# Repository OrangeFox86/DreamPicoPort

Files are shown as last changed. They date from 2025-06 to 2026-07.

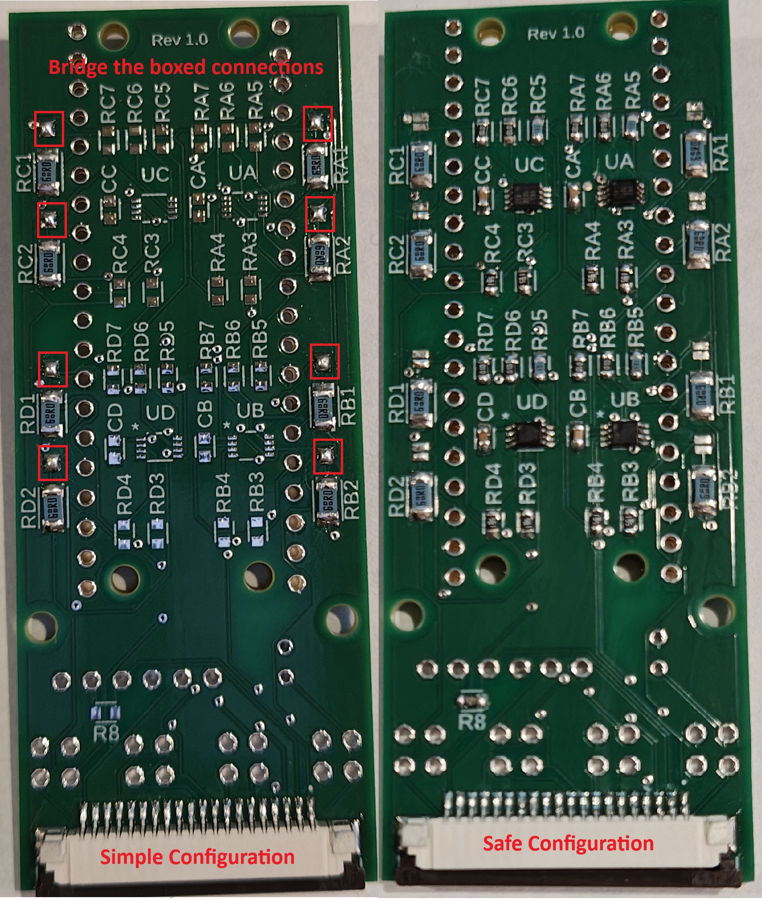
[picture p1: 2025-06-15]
pcb/board-examples.jpg

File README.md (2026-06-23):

# DreamPicoPort (formally DreamcastControllerUsbPico)

Using a Raspberry Pi Pico, DreamPicoPort enables USB interfacing with a Dreamcast or its controllers and peripherals, functioning in either host mode or client mode as depicted below.

Looking for instructions on how to use this with flycast? [Bring me to it!](https://github.com/OrangeFox86/DreamPicoPort/wiki/*-Host-Mode-Installation-Guide-(for-use-with-Flycast))

| Host Mode | Client Mode |
| --- | --- |
| host mode | client mode |

This platform may easily be forked and adapted for other interfacing needs. Feel free to do so under the conditions of the supplied [LICENSE.md](LICENSE.md).

Refer to the [releases](https://github.com/OrangeFox86/DreamPicoPort/releases) page for current progress. Refer to the [issues](https://github.com/OrangeFox86/DreamPicoPort/issues) tab for things left to be implemented and known bugs.

---

# General Disclaimer

Proceed at your own risk! I am not liable for any damage that may occur due to the use of any provided schematics, firmware, or any other recommendations made within this project (see [LICENSE.md](LICENSE.md)). There is risk of damage to any attached hardware (ex: USB port, Dreamcast peripheral, or Dreamcast) if circuitry is improperly handled.

---

# Quick Installation Guide

These instructions have been moved to [the wiki](https://github.com/OrangeFox86/DreamPicoPort/wiki/Installation-Guide).

# Build Instructions (for Linux and Windows)

If running under Windows, install [WSL](https://docs.microsoft.com/en-us/windows/wsl/install) and your desired flavor of Linux. I recommend using Ubuntu 22.04 as that is what I have used for development. Then the steps below may be run within your WSL instance.

1. Install git, cmake, and gcc-arm-none-eabi compiler by running the following commands
```bash
sudo apt update
sudo apt -y install git cmake gcc-arm-none-eabi
```

2. (optional) In order to run and debug tests, install standard gcc compilers and gdb by running the following
```bash
sudo apt -y install build-essential gdb
```

3. Clone this repo then cd into the created directory
```bash
git clone https://github.com/Tails86/DreamPicoPort.git
cd DreamPicoPort
```

4. Pull down the pico SDK (this project now uses a fork of the SDK - it will no longer compile under the standard SDK)
```bash
git submodule update --recursive --init
```
Hint: if you have issues building, the easiest way to correct any submodule synchronization issue is to delete the `ext/pico-sdk` directory (ex: `rm -rf ext/pico-sdk`), restore the directory `git restore ext/pico-sdk`, and then re-run the above submodule update command.

5. (optional) Build and run tests - this runs core lib unit tests locally
```bash
./run_tests.sh
```

6. Execute the build script
```bash
./build.sh
```

After build completes, binaries should be located under `dist/`. Pre-built release binaries may be found [here](https://github.com/OrangeFox86/DreamPicoPort/releases).

This project may be opened in vscode. In vscode, the default shortcut `ctrl+shift+b` will build the project. The default shortcut `F5` will run tests with gdb for local debugging. Open the terminal tab after executing tests with debugging to see the results.

---

# Maple Bus Implementation

The Maple Bus is a serial communications protocol which Dreamcast uses to communicate with controllers and other peripherals. Refer to documentation [here](https://dreamcast.wiki/Maple_bus) for general information about the Maple Bus.

## Why the RP2040/RP2350 are Game Changers for Emulating Communication Protocols

To emulate a bespoke communication protocol such as the Maple Bus on an MCU, one would usually either need to add extra hardware or bit bang the interface. This is not true with the RP2040/RP2350 and their PIO. Think of it as several extra small processors on the side using a special machine language purpose-built for handling I/O. This means communication can be offloaded to the PIO and only check on them after an interrupt is activated or a timeout has elapsed. Check out [maple_in.pio](src/hal/MapleBus/maple_in.pio) and [maple_out.pio](src/hal/MapleBus/maple_out.pio) to see the PIO code.

Luckily, the RP2040/RP2350 come with 2 PIO blocks each with 4 separate state machines. This means that the RP2040/RP2350 can easily emulate 4 separate controller interfaces, each at full speed!

## Interfacing with the PIO State Machines

The [MapleBus class](src/hal/MapleBus/MapleBus.hpp) operates as the interface between the microcontroller's code and the PIO state machines, [maple_in.pio](src/hal/MapleBus/maple_in.pio) and [maple_out.pio](src/hal/MapleBus/maple_out.pio).

Using 2 separate PIO blocks for reading and writing is necessary because each PIO block can only hold up to 32 instructions, and this interface is too complex to fit both read and write into a single block. Therefore, the write state machine is completely stopped before starting the read state machine for the targeted bus. Switching state machines is fast enough that there shouldn't be a problem. Testing showed the handoff always occurs within 1 microsecond after bringing the bus back to neutral. A device on the Maple Bus starts responding some time after 50 microseconds from the point of the bus going neutral after an end sequence. This ensures that a response is always captured.

The following lays out the phases of the state machine handled within the MapleBus class.

<p align="center">
  MapleBus Class State Machine
</p>

### PIO Data Handoff

When the write method is called, data is loaded into the Direct Memory Access (DMA) channel designated for use with the maple_out state machine in the MapleBus instance. The DMA will automatically load data onto the TX FIFO of the output PIO state machine so it won't stall waiting for more data.

The first 32-bit word loaded onto the output DMA is how many transmission bits will follow. In order for the state machine to process things properly, `(x - 8) % 32 == 0 && x >= 40` must be true where x is the value of that first 32-bit word i.e. every word is 32 bits long and at least a frame word (32 bits) plus a CRC byte (8 bits) are in the packet. This value needs to be loaded with byte order flipped because byte swap is enabled in the DMA so that all other words are written in the correct byte order. The rest of the data loaded into DMA is the entirety of a single packet as a uint32 array. The last uint32 value holds the 8-bit CRC.

A blocking IRQ is triggered once the maple_out state machine completes the transfer. This then allows MapleBus to stop the maple_out state machine and start the maple_in state machine.

A Direct Memory Access (DMA) channel is setup to automatically pop items off of the RX FIFO of the maple_in state machine so that the maple_in state machine doesn't stall while reading. Once the IRQ is triggered by the maple_in state machine, MapleBus stops the state machine and reads from data in the DMA.

## Generating Maple Bus Output

The [maple_out PIO state machine](src/hal/MapleBus/maple_out.pio) handles Maple Bus output. Data is generated by following the signal definition [here](https://dreamcast.wiki/Maple_bus#Maple_Bus_Signals).

## Sampling Maple Bus Input

The [maple_in PIO state machine](src/hal/MapleBus/maple_in.pio) handles Maple Bus input. Some concessions had to be made in order to handle all input operations within the 32 instruction set limit of the input PIO block. The following are the most notable limitations.
- Only a standard data packet may be sampled
    - The Maple Bus protocol has different types of packets depending on how many times B pulses in the start sequence, but those packets are ignored in this implementation
- The full end sequence is not sampled
    - The packet length in the frame word plus the CRC are relied upon during post-processing in order to verify that the received packet is valid

### Sampling the Start Sequence

The input PIO state machine will wait until **A** transitions LOW and then count how many times **B** toggles LOW then HIGH while making sure **A** doesn't transition HIGH until after **B** transitions HIGH. If the toggle count isn't 4, then the state machine keeps waiting. Otherwise, the state machine signals the application with a non-blocking IRQ and continues to the next phase where data bits are sampled.

### Sampling Data Bits

For each bit, the state machine first waits for the designated clock to be HIGH before proceeding. Then once this line transitions to LOW, the state of the designated data line is sampled. State transitions of the designated data line are ignored except for the case when sensing the end sequence is required as described in the next section.

### Sampling the End Sequence

Whenever **A** is designated as the clock, the input PIO state machine will detect when **B** toggles HIGH then LOW while **A** remains HIGH. It is assumed that this is the beginning of the end sequence since this is not a normal behavior during data transmission. The state machine will then block on an IRQ so that the application can handle the received data.

---

# Appendix A: Abbreviations and Definitions

- `0x` Prefix: The following value is hex format
- Byte: Data consisting of 8 consecutive bits
- DMA: Direct Memory Access
- LSB: Least Significant Byte
- LSb: Least Significant bit
- MSB: Most Significant Byte
- MSb: Most Significant bit
- Nibble: Data consisting of 4 consecutive bits
- PIO: Programmable Input/Output
- SDCK: Serial Data and Clock I/O
- Word: Data consisting of 32 consecutive bits

---

# External Resources

**Maple Bus Resources**

https://archive.org/details/MaplePatent/page/n7/mode/1up

http://mc.pp.se/dc/maplebus.html and http://mc.pp.se/dc/controller.html

https://tech-en.netlify.app/articles/en540236/index.html

https://www.raphnet.net/programmation/dreamcast_usb/index_en.php

https://web.archive.org/web/20100425041817/http://www.maushammer.com/vmu.html

https://hackaday.io/project/170365-blueretro/log/180790-evolution-of-segas-io-interface-from-sg-1000-to-saturn

https://segaretro.org/History_of_the_Sega_Dreamcast/Development

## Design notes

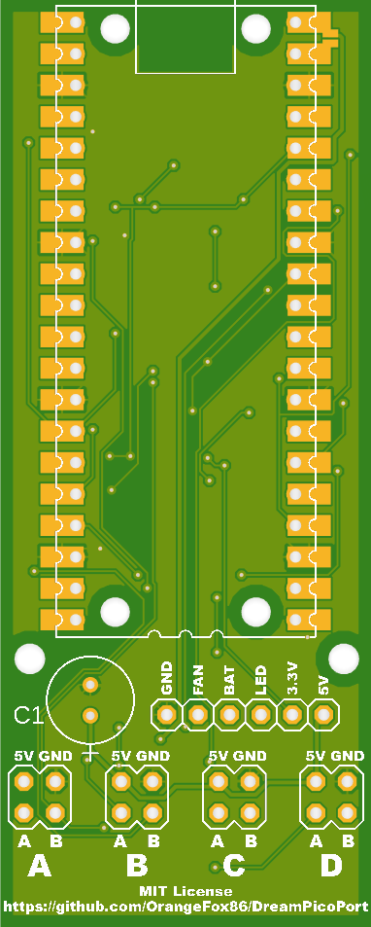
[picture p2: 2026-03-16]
pcb/board-top.png

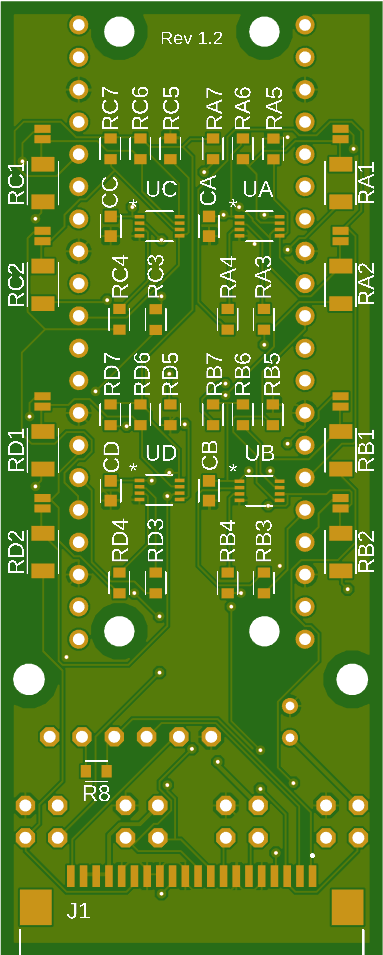
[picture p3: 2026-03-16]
pcb/board-bottom.png

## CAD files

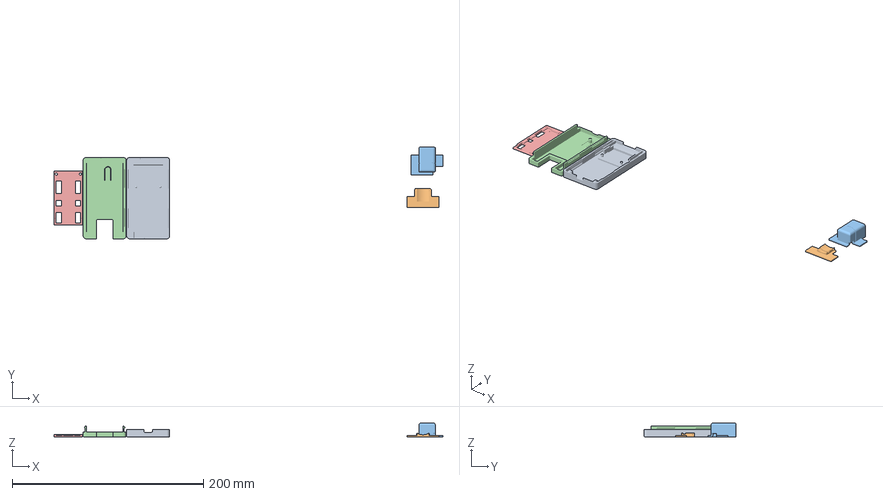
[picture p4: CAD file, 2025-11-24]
3d_objects/DPP-Case-1P-BambuStudio.3mf
406.7 x 95.8 x 15.0 mm
DPP-Case-Bottom
DPP-Case-DC-Connector-Bottom
DPP-Case-DC-Connector-Top
DPP-Case-Top
DPP-Dummy-Board

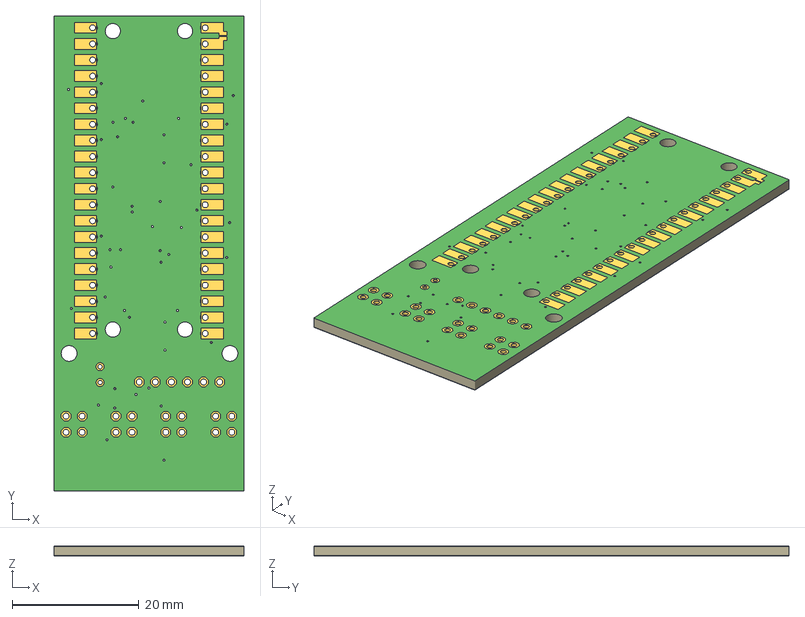
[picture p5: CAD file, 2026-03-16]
pcb/DreamPicoPortSchem.3mf
30.0 x 75.0 x 1.64 mm
Board
CopperHoles

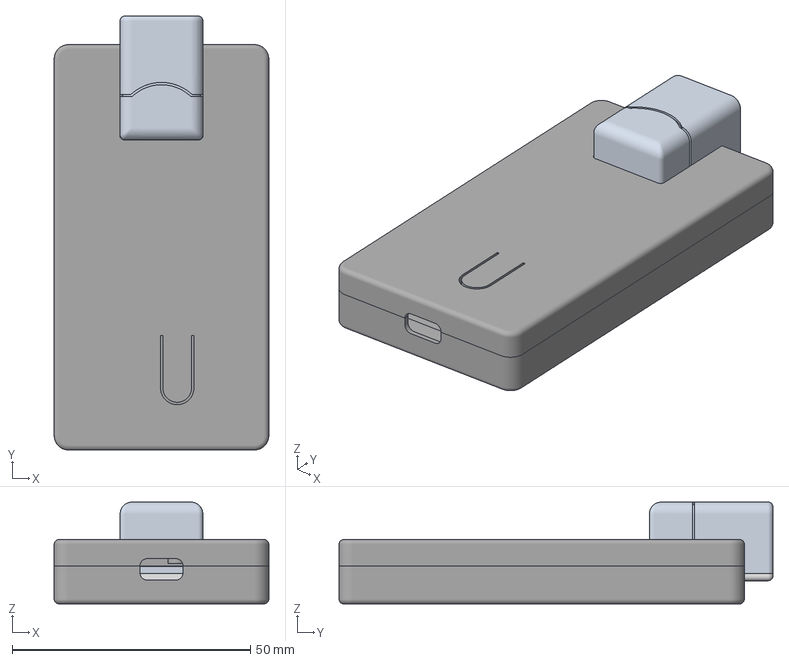
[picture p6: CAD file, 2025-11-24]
3d_objects/DPP-Case-1P-raw.3mf
45.0 x 91.0 x 21.4 mm
DPP-Case-Bottom
DPP-Case-DC-Connector-Bottom
DPP-Case-DC-Connector-Top
DPP-Case-Top

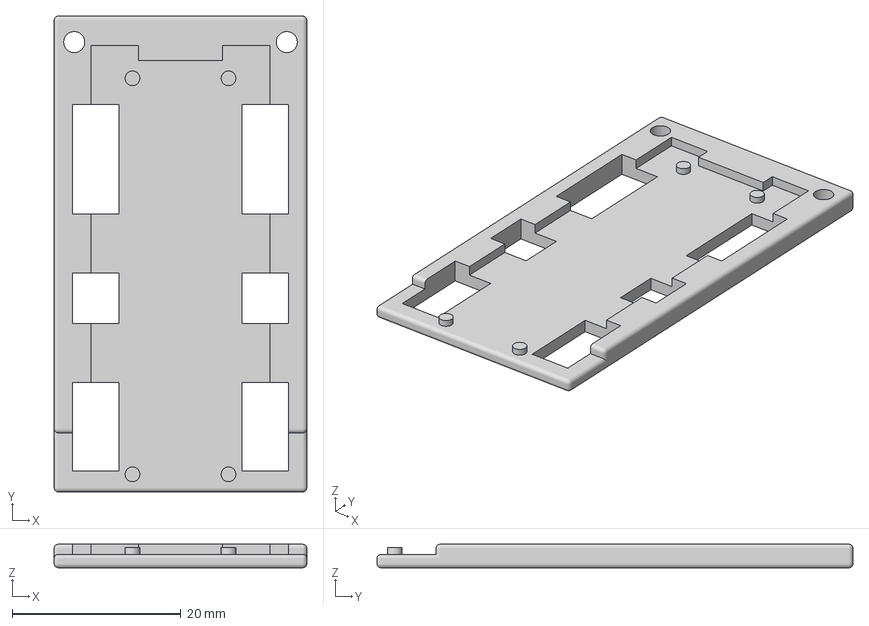
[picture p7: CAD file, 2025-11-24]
3d_objects/DPP-Dummy-Board-raw.3mf
30.0 x 56.5 x 2.80 mm

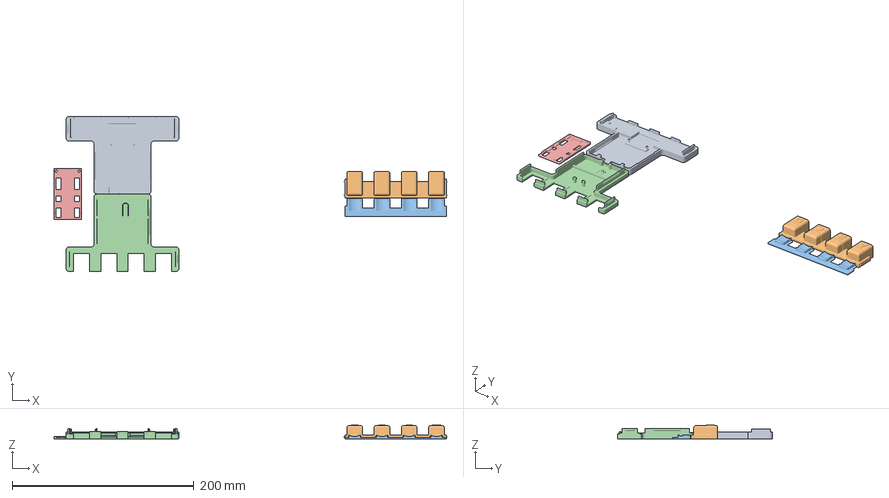
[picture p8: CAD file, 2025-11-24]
3d_objects/DPP-Case-4P-BambuStudio.3mf
432.5 x 170.5 x 15.6 mm
DPP-Case-4P-Bottom
DPP-Case-4P-DC-Connector-Top
DPP-Case-4P-DC-Connector-Bottom
DPP-Case-4P-Top-Solid
DPP-Dummy-Board

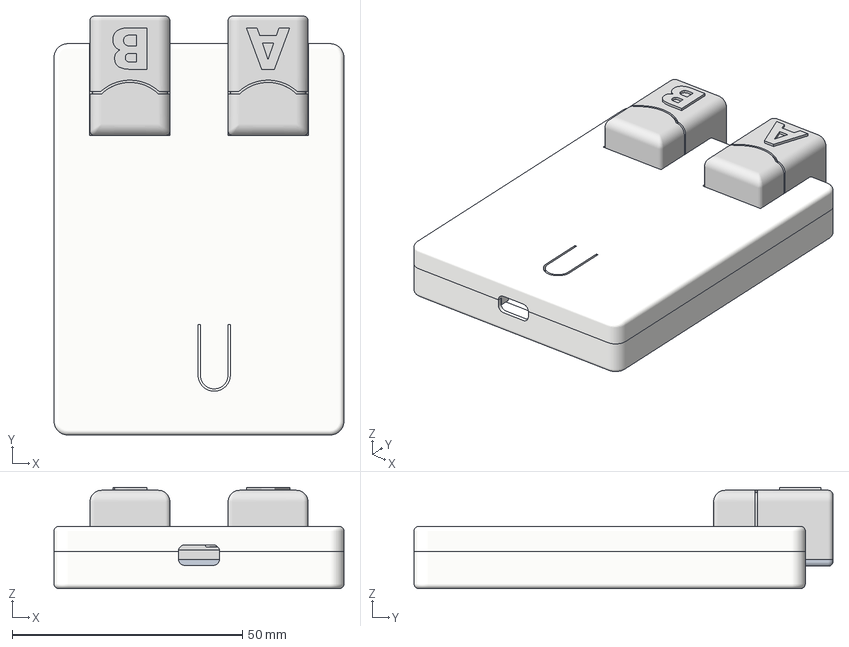
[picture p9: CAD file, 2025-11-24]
3d_objects/DPP-Case-2P-raw.3mf
63.0 x 91.0 x 21.9 mm
DPP-Case-2P-Bottom
DPP-Case-2P-DC-Connector-Bottom
DPP-Case-2P-DC-Connector-Top
DPP-Case-2P-Top-Solid

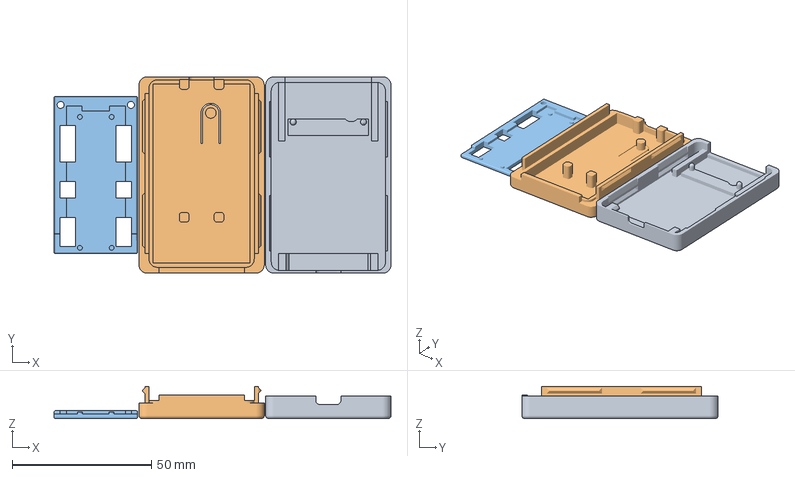
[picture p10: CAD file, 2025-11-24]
3d_objects/DPP-Case-Ribbon-BambuStudio.3mf
121.0 x 70.5 x 11.5 mm
DPP-Case-Ribbon-Bottom
DPP-Case-Ribbon-Top
DPP-Dummy-Board

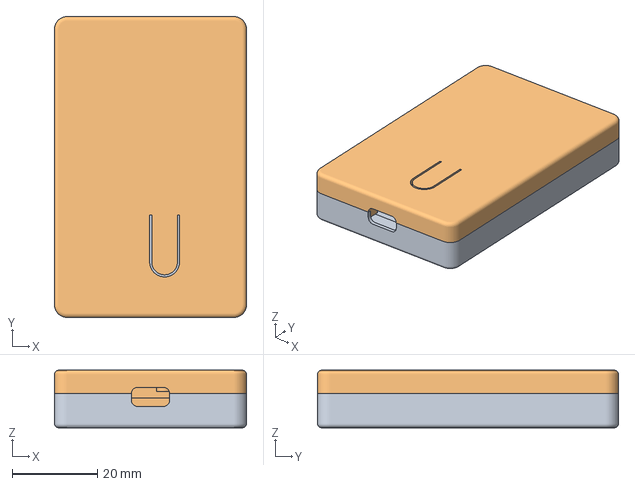
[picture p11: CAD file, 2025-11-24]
3d_objects/DPP-Case-Ribbon-raw.3mf
45.0 x 70.5 x 13.5 mm
DPP-Case-Ribbon-Bottom
DPP-Case-Ribbon-Top

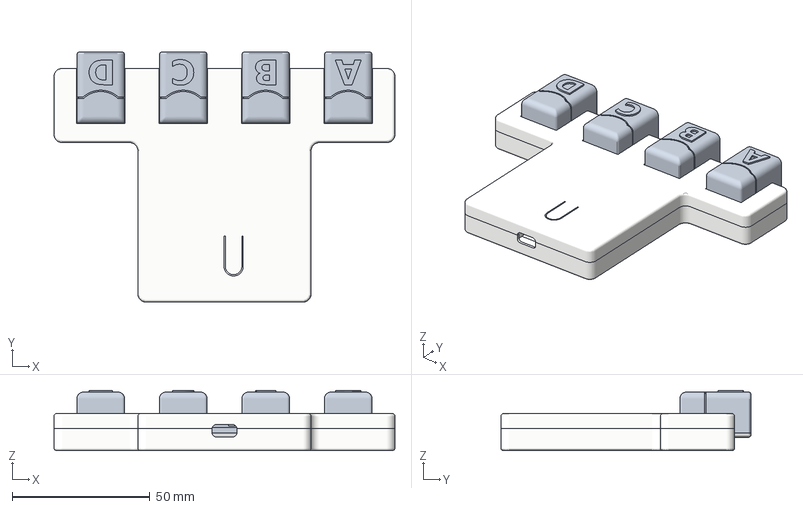
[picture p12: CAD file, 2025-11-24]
3d_objects/DPP-Case-4P-raw.3mf
124.0 x 91.0 x 21.9 mm
DPP-Case-4P-Bottom
DPP-Case-4P-DC-Connector-Bottom
DPP-Case-4P-DC-Connector-Top
DPP-Case-4P-Top-Solid

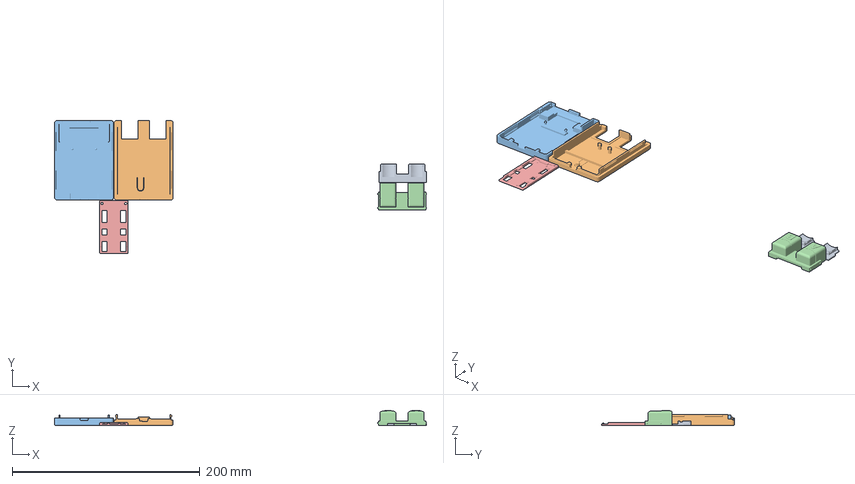
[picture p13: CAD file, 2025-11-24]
3d_objects/DPP-Case-2P-BambuStudio.3mf
396.5 x 142.0 x 15.6 mm
DPP-Case-2P-DC-Connector-Bottom
DPP-Case-2P-Top-Solid
DPP-Case-2P-Bottom
DPP-Case-2P-DC-Connector-Top
DPP-Dummy-Board

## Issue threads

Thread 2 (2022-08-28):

Removing and reinserting VMU occasionally causes communication to fail

Tails86, 2022-08-28:
To reproduce:

- Plug in controller
- Plug VMU (without battery) into controller, and wait until power on beep completes
- Remove VMU
- Repeat above two until controller stops responding completely

Tails86, 2022-08-28:
When a VMU is plugged in and initially powers up, the controller completely stops communicating for a while. Normally, the microcontroller will detect this and internally disconnect then continually ask for status until it responds again. This matches how the Dreamcast operates. Unlike the Dreamcast, this implementation sometimes puts the controller in a non-functioning state until it is reset. One peculiar thing I noticed is during the VMU initialization beep, logic LOW sits about 1.3 to 1.4 V when measuring SDCK lines at the controller. On the Dreamcast, the same sort of oddness happens, but logic LOW sits about 1.0 to 1.1 V. This could be because I'm using slightly higher inline resistors??? I'll try reducing these values later and see if that helps.

Tails86, 2022-08-28:
Changing resistor values makes no difference

Tails86, 2022-09-04:
Occasionally sending reset sequence resolves this. I tested this in the "Add-Reset" branch. This implementation became stale, and I wasn't satisfied with how it was implemented anyway. I'll add this in sometime in the future

Tails86, 2022-09-05:
I found that the pico has some resistance on its output already. I reduced the added resistance on the GPIO to match the total resistance that a Dreamcast has. This didn't seem to help much.

I then played around with a real Dreamcast and was actually able to reproduce this issue there. Since this is an issue on a real system too, I don't think there is much I can do about it. I'm keeping this issue open though so I can keep thinking of ways this can be fixed.

Tails86, 2023-01-02:
The supposed reset sequence, 14 pulses on msckb while mscka is low, does not do anything to get the controller out of this state

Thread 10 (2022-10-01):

Add USB Mass Storage Device for VMU Memory

Tails86, 2022-10-01:

hpx1984, 2022-11-18:
Hi Sir
how to use this function?

Tails86, 2022-11-18:
It's an open item. I haven't done any development for it yet, but I
envision setting up a mass storage device with maybe directory structure of
all files found. Or maybe just the raw data files of each VMU which could
then be imported into an emulator.

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

Tails86, 2022-11-20:
I'm diving into it now - probably another week or two, depending on how much free time I find. FAT16 drive is setup with placeholders for the raw memory files. It's very likely that these files can be dumped right to/from redream vmu bin files (haven't checked that yet, but the file size of redream files is exactly the size of memory available in a VMU).
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

Tails86, 2022-11-25:
I tweaked things a bit so that files only show up when the associated memory unit is attached. I confirmed that the file is compatible with redream. Files at the moment are read only.

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

Closed 2022-11-25.

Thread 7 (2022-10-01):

Host: Add USB HID Gamepad Force Feedback for Vibration

Tails86, 2022-10-01:

Tails86, 2023-01-01:
I was able to get the right FFB descriptors, but it seems like at least Windows is not picking it up/using it correctly. Drivers may be needed.

Tails86, 2023-11-19:
I've struggled with this and failed to come up with anything. Implementing as XInput is likely the best path forward.

Closed 2023-11-19.

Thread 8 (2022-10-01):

Host: Interface Screen to USB

Tails86, 2022-10-01:

Tails86, 2025-03-17:
Moving forward with current direct Flycast integration, so this is no longer necessary

Closed 2025-03-17.

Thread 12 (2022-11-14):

DC controller no functional when test in Window10 and XP's game controller test App

hpx1984, 2022-11-14:
Dear Sir

i used p2040 board and Main.uf2, when this board to PC(connect 1set DC controller on the board) ,the game controller test app can saw 4items "4P"
but my DC controller no functional on game controller test APP
please help me for fix it if you did know how to fix the problem
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

Tails86, 2022-11-14:
Thank you for your interest in this project!

I assume you are using this release, right? https://github.com/OrangeFox86/DreamcastControllerUsbPico/releases/tag/v0.1

The LED on the board should be on once connected to USB and off when any button is pressed on the controller or the analog stick is moved. That should be a quick test to make sure basic controller communication is working.

I have been mainly using Windows 11 to develop this and https://gamepad-tester.com/ to quickly test things out. You should see P1, P2, P3, P4 there and pressing buttons should register.

I have a feeling that Windows is going to have trouble labeling the 4 controllers right in some circumstances (possibly with older versions) which is why it looks like P4 is labeled for all on your system. I may put in a fix in the future to only enumerate connected controllers so that it will at least look fine when a single controller is connected. I can get you a custom single player variant of the uf2 in the meantime if it seems like that is the issue here. How many controllers are you trying to wire up at the moment?

hpx1984, 2022-11-14:
Hi Sir,
thanks your replied any supported ,
yes， i used this FW on my board
the LED always on when i pressed any button
i want connect 4 controllers but at the first i just connected one for test , if it is working fine then i will go on for connect more controller
i used a controller extension cable for soldered on PI Board and then connected my 1st controller on it

i got this but still no action on the page when i pressed button
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

Tails86, 2022-11-14:
Looks like that page enumerates the controller properly. So far so good!

It sounds like you're not getting communication with the controller.

Check your wiring. You made me realize that I forgot to document the pinout at the port. Refer to the image here: http://www.raphnet-tech.com/products/dreamcast_usb_circuit/dc_connector_pinout.png
1: SDCKA
2: +5V
3: GND
4: GND
5: SDCKB

That should correlate to the schematic here:
https://raw.githubusercontent.com/OrangeFox86/DreamcastControllerUsbPico/main/images/schematic.png

hpx1984, 2022-11-15:
hi Sir
double checked the connection it is correct
now i cut the extension cable for short the cable on connection but the system still not working,
any i tried two boards also got same problem
maybe i need to dis-assemble the controller for make sure it is the sega official controller
i had 8sets DC controller on hand but all can't working on this system , but its is working on DC
i will try to find where the problem ,if you have any comment please also let my know for try

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

Tails86, 2022-11-15:
I see where the confusion is. The schematic I used called out physical pin numbers, not the GPIO pin numbers. The top image is what my schematic was drawn for.
14 -> GP10
15 -> GP11
16 -> GP12
17 -> GP13
24 -> GP18
25 -> GP19
26 -> GP20
27 -> GP21
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

Looks like the bottom one you're using lists out the actual GPIO pin numbers, so 10-13 and 18-21 would be the right pins on that one.

I'll update my schematic to make that clearer as well.

hpx1984, 2022-11-15:
Hi Sir

Great
now the system can working，many thanks your great help

now seems perfect if can fix the 4-P4 issue

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

Tails86, 2022-11-15:
I've seen this happen before when using generic HID gamepad descriptors, and it seems to be a long-known bug with Windows DirectX/drivers from forum posts I have gone through. It still happens in Windows 11 now that I've actually looked. What's worse is that Windows doesn't even seem to sort them in the proper order. I'm assuming that the web interface is grabbing raw data instead of going through DirectX which is why things show up properly at gamepad-tester.com.

I _think_ my only options here would be to either use a different USB descriptor for the device like xinput or spin up my own driver. Using xinput seems to be what most controller manufacturers are doing these days in order to avoid writing drivers. I started playing with xinput, but then I got distracted with other things. It will likely be a few more months before this gets fixed.

[This project](https://github.com/fluffymadness/tinyusb-xinput) will likely be very helpful.

hpx1984, 2022-11-18:
many thanks your quickly support ，Sir
the function is good that is first important, so this just a very smaller problem

but this project really a great project for let peoples enjoy DC game on PC like DC console
and this project has great potential as one day it may grow to a family project for support other game console ,like PSXControllerUsbPico, NGCControllerUsbPico, N64ControllerUsbPico,PCEControllerUsbPico,3DOControllerUsbPico...........
hope can see in future

Tails86, 2022-11-27:
Opened up https://github.com/OrangeFox86/DreamcastControllerUsbPico/issues/18 to fix that bug, and I'm closing this thread out

Closed 2022-11-27.

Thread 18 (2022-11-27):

Windows doesn't parse players 1 through 4 labels properly

Tails86, 2022-11-27:
It seems to be a long-known bug with Windows DirectX/drivers from forum posts I have gone through. It still happens in Windows 11 now that I've actually looked. What's worse is that Windows doesn't even seem to sort them in the proper order. I'm assuming that the web interface is grabbing raw data instead of going through DirectX which is why things show up properly at gamepad-tester.com.

I think my only options here would be to either use a different USB descriptor for the device like xinput or spin up my own driver. Using xinput seems to be what most controller manufacturers are doing these days in order to avoid writing drivers.

[This project](https://github.com/fluffymadness/tinyusb-xinput) will likely be very helpful.

multigamesystem, 2023-11-01:
I'm also seeing similar behaviour in RetroArch via Linux.  Which is breaking functionality please make it so only one controller is recognized when one controller is plugged in.  The same issue is happening that when one controller is plugged in it is automatically set to P4.  I've only wired one controller input up as according to your readme.

Tails86, 2025-01-25:
I'm moving forward with just supporting compatibility through the serial interface to whatever emulator wants to interface with this (flycast support is in dev at the moment, but only for 1p mode). I don't think there is anything that can be done with how Windows handles things.

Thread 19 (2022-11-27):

Windows does not try to re-pull FAT table after UNIT ATTENTION sent

Tails86, 2022-11-27:
When the file system adds or removes a file, it sends UNIT ATTENTION to the host so it knows something changed. Windows, however, does not reread the FAT, even when F5 is pressed. I've found *some* help in resending UNIT ATTENTION until read of FAT is detected, but it only works once. I haven't confirmed if the host is actually receiving UNIT ATTENTION.

Figure out what needs to be done in order to force Windows to recheck the FAT.

Tails86, 2022-12-25:
There seems to be no reliable way to accomplish this. I don't want to force a disconnect, so it may be best just to always show 8 devices when the drive attaches. Trying to read vmu that is not attached should then cause an error.

Tails86, 2022-12-26:
It seems like the consensus on stack overflow and other sites that it is bad practice for a mass storage device to modify itself while attached to the host. Seems right to me 😆 I'm changing the purpose of this issue.

Tails86, 2022-12-26:
Purpose:
- All 8 possible VMUs to be presented to the host when any memory unit is detected
- Host is allowed to modify the FAT in any way it would like as long as it's only trying to create or modify entries which have the same file name as something already on the file system
    - Internally use the FAT as "truth" in order to determine where to write to

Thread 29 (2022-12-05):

Expose raw maple bus communication to USB CDC (serial) device

Tails86, 2022-12-05:
Add feature to communicate directly with the maple bus through a USB CDC device. Make it optional (enabled with a jumper) if it starts to interfere with normal communication.

Closed 2022-12-18.

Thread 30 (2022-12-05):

Host: Support VMU beeps through USB

Tails86, 2022-12-05:

Tails86, 2023-12-09:
I discovered this VMU interface never really worked right with the original - only high pitch tones can be generated through the maple bus interface to a real VMU. This didn't seem to ever be used.

Closed 2023-12-09.

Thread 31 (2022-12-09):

Fault while using Retro Fighters controller

Tails86, 2022-12-09:
To reproduce:

1. Plug in Retro Fighters controller and verify controls are working
2. Wait 15 minutes
3. Check gamepad controls again

Expected response:
Controls no longer working

I haven't experienced this with an OEM controller yet.

Tails86, 2022-12-18:
On failure when SHOW_DEBUG_MESSAGES is enabled, I see the message "P1 disconnected", and then no further communication. No communication is seen on the maple bus at this time. The USB CDC interface still echos data which tells me that the core in charge of USB is still working fine. It's just the core in charge of Maple Bus.

I recorded the Maple Bus output until crash. Communication chugs along fine then randomly crashes as the first 2 bits are being outputted. 15 us later, both lines go back high.

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

Tails86, 2022-12-18:
I ran again with analog recording. This shows that not only is this repeatable, but the slow return back HIGH tells me everything shit the bed rather abruptly - probably returning IO all back to high impedance input.
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

I probably won't be able to figure this out until I hook up a proper debugger (which I've been meaning to do, but I haven't had a reason to do it yet)

Tails86, 2022-12-18:
Issuing "h" to USB CDC after this occurs does nothing which means the maple bus core is indeed locked up

Tails86, 2022-12-18:
I found the issue causing this and committed a temporary fix here: https://github.com/OrangeFox86/DreamcastControllerUsbPico/commit/322c4f4dbb9054719bd1e02a314389a1c1a44df3

I think the problem is that TransmissionTimeliner::writeTask() may hold onto a popped transmission until the Maple Bus gets freed. Meanwhile, it's possible for the node to remove the peripheral from its list (deleting it). This invalidates the pointer that is held within mNextTx. Things would crash once txStarted() is called on the invalid pointer.

Something else is not sitting with me right though. The controller shouldn't have been disconnected in the first place. This seems to happen occasionally with the Retro Fighters controller. Perhaps occasional dropouts should be tolerated?

Closed 2022-12-18.

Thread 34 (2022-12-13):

Add support for all different types of controllers

Tails86, 2022-12-13:
I obtained some documentation on button layout for different controllers - support all different types in the controller peripheral. Apparently, fishing rod DOES need to be handled differently. doh!

Tails86, 2023-01-01:
It looks like all controller definitions overlap, and they will send centered or unpressed values if the button/stick/trigger isn't used. Only changed names.

Closed 2023-01-01.

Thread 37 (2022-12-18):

Look further into Retro Fighters controller

Tails86, 2022-12-18:
Issue #31 addressed an issue by allowing 2 consecutive communication failures. Only on 3rd failure would the controller disconnect. I'm not entirely convinced this is an issue with the controller but instead with the way bits are read (I seem to recall my logic analyzer properly picking up the data when things failed). This issue just serves as a reminder for me to go back and look at any other funny business with bit sampling.

Tails86, 2022-12-21:
There does indeed seem to still be an issue here. It doesn't happen very often, but this happens randomly during a normal write sequence to poll the controller.
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

Nothing about the start of this transmission seems odd. It happens 15.6 ms after the end of the previous transmission which is normal. The next communication fails because a proper end sequence hadn't been written. Then the one after that succeeds.

Tails86, 2022-12-22:
- This error happens much more frequently when SHOW_DEBUG_MESSAGES is set to true
- This also seems to happen more frequently when multiple controllers added
- Added a 3 microsecond delay right after DMA is loaded, and that made no difference to the number of bits transmitted before failure
    - Smells like an interrupt issue

Tails86, 2022-12-22:
It does look like Retro Fighters controller does go nutty like this which may explain why I had more issues with this controller than others
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

Closed 2022-12-22.

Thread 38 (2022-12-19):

Fix some CDC interface issues

Tails86, 2022-12-19:
1. Handle \r

Testing this stuff on PuTTY on windows is problematic. It seems that PuTTY sends '\r' on enter (not \r\n as expected). Commands are never parsed in that case. It probably makes sense to start parsing a command on either \r or \n.

2. It may make sense to output \r\n instead of just \n for universal compatibility

3. Multiple commands in same line may not process

mCommandReady is cleared even if mulptiple \n may exist - only one \n is parsed

4. tud_task() gets called from the maple bus core on printf() - I don't think this is right, and I'm a little surprised this still works

5. Handling backspace isn't working properly

Tails86, 2022-12-20:
(4) doesn't seem to be an issue because tinyusb uses mutexes to guard certain things.

Closed 2022-12-20.

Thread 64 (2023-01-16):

Client: Make a storage variant with non-volatile memory

Tails86, 2023-01-16:
The DreamcastStorage class in client currently reads from and writes to RAM which was done to simplify things in order to test capabilities. In order to instead use flash memory, both cores need to be executing from RAM or be otherwise disabled while flash is being written to. The flag -DPICO_NO_FLASH=1 may be used to load and run all code from RAM on startup. This limits the program size to the size of RAM (256 KB), but it will relieve that constraint completely.

Secondly, it takes too long to write 512 bytes in line with normal Maple Bus execution. The best option would be to use the second core to write flash, as needed. Some care would then need to be taken with the read operation to make sure:
- read from flash doesn't happen at the same time flash is being written
- read operation isn't reading stale data from flash while some data is waiting to be written to the target address range

It may be helpful to see if it is possible to send the start sequence out first as a way to hold the line in a busy state while read or write operations are being carried out.

It may be beneficial to make 2 variants of client: one with volatile memory and one with non-volatile memory. There are use-cases where volatility of memory doesn't matter, such as one where this system is attached to a PC host, and that host is feeding memory to the pico. Using onboard flash adds too much complexity in that case.

Closed 2023-01-22.

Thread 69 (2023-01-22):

Client: Setup USB in host mode to support xinput controllers

Tails86, 2023-01-22:

Tails86, 2023-02-06:
This is a great repo to reference: https://github.com/Ryzee119/tusb_xinput

Tails86, 2025-03-03:
http://usb4maple.wikidot.com/
Seems like this project is more fleshed out than client mode here - it has xinput support

clach04, 2025-05-25:
Cross reference to another xinput (+others) pico project https://github.com/wiredopposite/OGX-Mini

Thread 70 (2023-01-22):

Host & Client: Implement using a bus transceiver in order to protect Pico and attached devices

Tails86, 2023-01-22:
The Pico is not able to source or sink any more than 50 mA on the I/O. This isn't an issue unless a fault occurs which would kill the Pico. Using a 2-bit bus transceiver which could source/sink higher current value per pin would be beneficial. Selecting one with good transient voltage suppression is desired. The transceiver will need to switch from output to input and back within 1 microsecond, and it must be able to handle pulse widths of 150 ns.

This involves setting up 4 new outputs in order to select the external transceiver direction. The documentation must then be updated to provide this as an option.

Tails86, 2023-01-24:
This seems like a good option to test with
https://www.digikey.com/en/products/detail/texas-instruments/SN74AXCH2T45DCUR/12165180

Tails86, 2023-02-27:
That chip works only when the "open line check" in MapleBus::writeInit() is disabled. This is because the chip has an embedded "Bus-Hold Latch" which is incompatible with weak pull-ups. There is a strong potential for the input to be latched low, and MapleBus will never write. I am looking for alternative chips.

Tails86, 2023-02-27:
This could potentially be useful, but it has more IO than is needed:
https://www.digikey.com/en/products/detail/texas-instruments/CD74HC243E/1506891
It also has a surface mount equivalent:
https://www.digikey.com/en/products/detail/rochester-electronics-llc/CD74HC243M/11546734

Tails86, 2023-02-27:
It has occurred to me that the "H" in the chip number means latching. The following is the TI chip without latching.
https://www.digikey.com/en/products/detail/texas-instruments/SN74AXC2T45QDCURQ1/15666789

Closed 2023-03-04.

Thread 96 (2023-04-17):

Client: Games that are "powered by Windows CE" respond too quickly for client executable

Tails86, 2023-04-17:
Games that are "powered by Windows CE" may respond within 1 microsecond after write completes. This is too fast for the client execution loop to handle. Some tweaks need to be made to MapleBus with this in mind.

Tails86, 2023-04-18:
- Automatically reload read within MapleBus
    - Don't force B back high - just let pullup slowly bring it back high (buys an extra millisecond or two)
    - Allow in.start() to transition to input rather than doing that in out.stop() - make that an option in out.stop() or define something like out.pause()
    - Consider making a combined out-in PIO state machine where out works on pre-loaded bit values (longer to load write, but faster to transition from out to in and use of 1 single PIO bank)
- The screen memory info doesn't match that of real VMU which seems to lock up the game
- Something else is going on with memory which the game doesn't like and marks memory same as "full"

Closed 2023-04-22.

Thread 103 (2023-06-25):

Client: Implement passive buzzer

Tails86, 2023-06-25:
Implement passive buzzer and connect to Timer's alarm.

Closed 2023-07-04.

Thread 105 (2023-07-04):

Host: Something done after 0.12 release affected communication

Tails86, 2023-07-04:
One of my client controller boards no longer communicates properly with the host once the host is updated with firmware on main. I currently can't explain why that is, especially since all OEM controllers and the other 2 custom boards I made all work. Once the host is flashed with version 0.12, the problem goes away. It seems to have to do with communication with VMU sub-peripheral.

Tails86, 2024-02-09:
This doesn't seem to be an issue anymore. I'm chalking it up to bad wiring

Closed 2024-02-09.

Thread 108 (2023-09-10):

Add a suggestion for the 2-bit Bus Transceiver chip (isolation circuitry)

ErykDarnowski, 2023-09-10:
For a novice in eletronics (like me) I'd be really helpful to see an example of the needed 2-bit Bus Transceiver. I've found a suggestion in this issue's comment: https://github.com/OrangeFox86/DreamcastControllerUsbPico/issues/70#issuecomment-1445623241 but it would be great if it were added to the `README.md` for someone in the future to see right away!

P.S.
I'm utterly amazed with this project! I've recently got interested in emulation and (among others) got myself a Dreamcast controller. I'd love to use the **VMU**, **Jump Pack** and perhaps even the **Microphone ** with an emulator, and this project (as far as I've seen) is my only hope, so huge props and congratulations on your work, hope to see more soon 😄

Ohh, and can't wait to build the hardware!

Tails86, 2023-09-10:
That is fair. I got a bit sidetracked over the last few months and didn't come back to flesh that documentation out. I have been using 74LVC2T45DC which is made by Nexperia and TI. I tied both Vcc inputs to 3.3 V, the DIR feeds to pin 5, and the signals feed to pins 2 and 3.

Where I bought them from:
https://www.digikey.com/en/products/detail/nexperia-usa-inc/74LVC2T45DC-125/2530595
https://www.digikey.com/en/products/detail/texas-instruments/SN74LVC2T45DCUR/657833

This is the one bit that makes this project less accessible since these chips only come in surface mount, 0.5 mm pitch SOP8. I found these little adapter boards which at least help with prototyping. It's still a giant pain to work with such small leads though.
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

I'll likely be able to find the time next month to start working on this project again. I hit a wall with trying to get the force feedback through USB working on Windows. It may be easiest to make the device look like an XBox controller, which seems to be what companies like 8BitDo do to get compatibility with Windows.

ErykDarnowski, 2023-09-11:
Sounds great!

Have you looked in to using **DirectInput** / **XInput**? That's the 2 PC input solutions my `SNES -> USB` Mayflash adapter provides (I'm pretty sure their other adapters rely on those too).

## Resources

- 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
- [What's the difference between Direct-Input and XInput](https://www.reddit.com/r/8bitdo/comments/q8zjxf/comment/hgts8q0/?utm_source=share&utm_medium=web2x&context=3)
- [Getting Started With XInput in Windows applications](https://learn.microsoft.com/en-us/windows/win32/xinput/getting-started-with-xinput)
- [Introduction to DirectInput](https://learn.microsoft.com/en-us/previous-versions/windows/desktop/ee418273(v=vs.85))

Tails86, 2023-09-11:
Yep! That's what I was talking about - XInput is what XBox controllers use. The main reasons I have been avoiding that is because it will force me to use specific VID/PID, and I would no longer be able to enumerate 4 controllers at once since I didn't see a way to add a hub in the current USB API.

ErykDarnowski, 2023-09-11:
Hmmm... **XInput** should support up to 4 controllers, but there's **DirectInput** too (which doesn't have such limitation)!

## Resources

- <https://gaming.stackexchange.com/a/358003>

Tails86, 2023-09-11:
What I was describing are limitations of the USB API at the device level. XInput requires certain things to be on certain endpoints and such, so I can't specify multiple controllers on the same device (like I'm currently doing with HID gamepad). In order to tell the host that there are multiple XInput controllers, you need to have it come up as 4 separate devices - this requires telling the host that my device is a USB hub, and then enumerate 4 separate USB devices on that hub. The USB API doesn't seem to allow for this kind of config yet (at least from the last time I checked a few months back, and maybe there is something I overlooked). It would be technically possible though... I am just not prepared to put in that effort unless it was already available in tinyusb 😆

Tails86, 2023-09-11:
This is as I suspected. No current support, and no support is planned:
https://github.com/hathach/tinyusb/discussions/1904

ErykDarnowski, 2023-09-11:
Ohhh! My bad, that's not good news! Also, thank you for the detailed explanation 😥

Closed 2023-11-19.

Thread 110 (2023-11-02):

cant compile it im not good at this lol

secretman28, 2023-11-02:
i wana change pin for remote toeasly and not use the bottom pin  wana change pin
// The start pin of the two-pin bus for each player
#define P1_BUS_START_PIN 10
#define P2_BUS_START_PIN 12
#define P3_BUS_START_PIN 2
#define P4_BUS_START_PIN 4
can some cone compile the thing and get me the u2f that i can flash it

or tell me what im doing wrong i can compile anything helse my vscode is set right

Tails86, 2023-11-02:
This is untested. Remove the .txt extension after downloading.
[host.uf2.txt](https://github.com/OrangeFox86/DreamcastControllerUsbPico/files/13233661/host.uf2.txt)

secretman28, 2023-11-02:
tanks! my freind rape windows to make it work in power shell vscode just dont want i dont know what im doing wrong, i can build any other pico project

Closed 2023-11-19.

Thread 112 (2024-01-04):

L trigger gets stuck held when playing Soul Calibur with Redream + Demul

multigamesystem, 2024-01-04:
When pressing the L trigger button while using Redream and playing Soul Calibur the L trigger gets stuck held until you reset the game or close the emulator.  Here is a video recreating the bug.

[https://youtu.be/HHU5TVLXMjk?si=yc71App9An33cQ1G](url)

ErykDarnowski, 2024-01-04:
Hey I think I encountered something similar.

In my case I tried to map some inputs in an emulator but every time I tried to remap something, one of the triggers would **force** itself in as it acted like it was constantly depressed (a state different than idle).

I took a look at the inputs in the Control Panel (like you did) and got the same weird behavior like the one in your YouTube video. Later I compared how the triggers acted to an **Xbox 360 controller** and noticed that they didn't start from the left (`0%`), but from the middle (`50%`) of the bar instead. That's when I decided to implement a quick fix and did [this](https://github.com/OrangeFox86/DreamcastControllerUsbPico/commit/48d4b3424466667c109ab892d5eb057045f1ab61).

multigamesystem, 2024-01-07:
The problem seems to not be a an issue with Retroarch oddly or at least I have noticed it being an issue when testing for the behavior with Soul Calibur.  Hopefully someone figures out a fix for this.

ErykDarnowski, 2024-01-07:
Ohhh...
Well, sorry to say I have no idea how Retroarch behaves with it (I just run my emulators on Windows).
I may test it when I have some free time however.

ErykDarnowski, 2024-01-08:
Ahh! My bad, I thought Retroarch was a Linux distro, but now I've learned that it's just a program.
But, if that's the case, than they issue should persist 🤔.

Tails86, 2024-01-22:
Possibly an interaction with USB HID controller somewhere in the OS or Retroarch?

To give a bit more context, [here](https://github.com/OrangeFox86/DreamcastControllerUsbPico/blob/42cbdd3c1b96ec0701aa757932964f9e78c66e10/src/hal/Usb/Client/Hid/UsbGamepadDreamcastControllerObserver.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) is where the value gets loaded into the USB interface. Then [here](https://github.com/OrangeFox86/DreamcastControllerUsbPico/blob/42cbdd3c1b96ec0701aa757932964f9e78c66e10/src/hal/Usb/Client/Hid/UsbGamepad.cpp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) is where the value is saved to the descriptor. This is using tiny USB's definition for HID controller [here](https://github.com/hathach/tinyusb/blob/938cae818f5f53887ad12e34189e6746dbce4889/src/class/hid/hid_device.h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) which limits the value between 0x81 and 0x7f. The host is supposed to recognize the first value as a 2's compliment negative value, so -127 to 127 should be what it recognizes the range as.

Tails86, 2024-02-03:
Showing the raw value on the calibration screens in the Windows gamepad tool provide the expected values. I tried Soul Calibur in Redream and wasn't able to reproduce.

I tried setting logical min/max to 0 to 255, but that caused more compatibility issues. I instead tried updating the minimum value from -127 to -128 and pushed that - it better correlates to Dreamcast mapping anyway. Maybe that will help? The Windows calibration tool is still jumpy, so I get the feeling there is some bug in Windows code.

multigamesystem, 2024-02-05:
> Showing the raw value on the calibration screens in the Windows gamepad tool provide the expected values. I tried Soul Calibur in Redream and wasn't able to reproduce.
>
> I tried setting logical min/max to 0 to 255, but that caused more compatibility issues. I instead tried updating the minimum value from -127 to -128 and pushed that - it better correlates to Dreamcast mapping anyway. Maybe that will help? The Windows calibration tool is still jumpy, so I get the feeling there is some bug in Windows code.

Could you link me to the updated .uf2 to test?

Tails86, 2024-02-05:
I published a new release with separate 4p and 1p variants
https://github.com/OrangeFox86/DreamcastControllerUsbPico/releases/tag/v0.13

Tails86, 2025-01-25:
Version 0.14 changes the range of the triggers (z values) to [0,127] and sends value in range [0,127]. This circumvents the compatibility issues I was talking about before while still keeping this in the positive range. I'm hoping that it will be interpreted as "positive" value by anything using it, but it seems the version of Windows and its drivers matters. Maybe now that 0 is considered "released" instead of -127 or -128, it may fix this issue?

multigamesystem, 2025-01-26:
> Version 0.14 changes the range of the triggers (z values) to [0,127] and sends value in range [0,127]. This circumvents the compatibility issues I was talking about before while still keeping this in the positive range. I'm hoping that it will be interpreted as "positive" value by anything using it, but it seems the version of Windows and its drivers matters. Maybe now that 0 is considered "released" instead of -127 or -128, it may fix this issue?

Thanks for the update and Ill test under Linux (Batocera).

Tails86, 2025-02-10:
I uninstalled and reinstalled the driver several times, and then it suddenly started happening to me too for both triggers in flycast. They will suddenly be interpreted as 50-100% pressed. I want to say this is a weird SDL interaction because the values being reported are the same as they've always been. Deleting [this line](https://github.com/flyinghead/flycast/blob/master/core/sdl/sdl_gamepad.h#L296) makes it start to function like it did before. I'll dig into this more this week.

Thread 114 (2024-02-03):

Client: Light gun support

Tails86, 2024-02-03:
Implement light gun emulation for client side

Tails86, 2024-02-06:
I was trying to aim the sample around center screen, but each lightgun game seemed to have their own slightly different interpretation of this signal. I'm assuming because the light gun detection starts at slightly different times (only about 20 microsecond difference here).

I just had this realization though. If I were the one to implement this lightgun protocol, I would coordinate the position based on 2 or more samples, assuming more than 1 line would be visible by the gun at any time. This would make sense based on some of the testing I was doing - I was only sending 1 sample, and House of the Dead 2 would flag an error if a sample was received in the second 16.6 ms only. This hints at some kind of algorithm combining samples to at least determine if the measurement is accurate. Now I'm wondering if this timing issue would go away if I sent 2 or 3 samples from connecting lines together. This would assume the combining algorithm on the Dreamcast is able to detect that a timing offset would need to be applied 🤞

Tails86, 2024-02-09:
Nope, that theory was a bust... It did change how Virtua Cop 2 processed the position, but now it's firing on the other side of nominal for some reason. No change in House of the Dead 2 or Confidential mission.

Tails86, 2025-01-25:
Proof of concept was developed, but this effort has been stalled

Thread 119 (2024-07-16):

printf error

Tails86, 2024-07-16:
printf errors suddenly show on compile - include stdio.h where necessary

Closed 2024-07-16.

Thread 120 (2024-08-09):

Potential for collaboration?

mackieks, 2024-08-09:
Hi! I am the author of [MaplePad](https://github.com/mackieks/MaplePad) which is a Dreamcast controller emulator based on Charlie Cole's Pop'n Music Controller project. It's primarily intended for Dreamcast portable builds, but has also found some modest success as a platform for custom arcade sticks.

Unfortunately MaplePad development has stalled due to my own skill issues and lack of time. The code is very spaghetti (I am not a SWE) but the only _major_ issues are with Windows CE games, due to their rapid Maple commands-- the Maple Bus system I inherited from Charlie's project can't keep up. I noticed you encountered the same issue with your implementation and fixed it last year.

Seeing as how you've pivoted to client-side peripherals, I would love to join forces somehow, or at least trade ideas. While I don't have much to offer your project in terms of clean or reusable code that you don't already have, it would be awesome to potentially bring in your PIO core to patch up MaplePad's final remaining bugs! I'm on discord if you want to talk there (yveltalgriffin)

Tails86, 2024-08-11:
You've got a cool project there. I have noticed it as I was developing. I think we started around the same time 😆

Yep, Windows CE was a struggle! I got it to work by holding the line low after write is complete until just before read is activated. Then the internal pull-up resistor is used to more slowly bring the line back high to buy more time. The signal looks a little ugly, but it works. I shot you a friend request.

Closed 2024-08-11.

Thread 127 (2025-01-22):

Maple Bus occasionally becomes unresponsive using Flycast

kosekmi, 2025-01-22:
Flycast PR: https://github.com/flyinghead/flycast/pull/1810
Originating PR: https://github.com/OrangeFox86/DreamcastControllerUsbPico/pull/124#issuecomment-2605298783

I noticed that sometimes the Maple Bus seems to be unresponsive to new messages. I.e., VMU LCD won't update, and Rumble stops working despite Maple Messages being send. The easy fix is re-connecting USB and everything works fine again. This observation is not new to the latest builds, I noticed this from the start.

I now found a way to reproduce this: On Sonic Adventure 2, select 1P Play -> Story -> Hero -> The Beginning (Or Stage Select -> City Escape). Skip cutscene, and start the game. From this point on, Maple Bus is unresponsive. To trigger LCD Update for example, quit SA2, and start any other Game - LCD won't update.
Interestingly, it keeps being responsive for serial commands like "h" which triggers the help. Then again, Maple messages being send outside Flycast (e.g., send default VMU screen via some serial terminal software) also won't trigger an LCD update.

So I figured that the handling within the microcontroller may have an issue processing Maple messages. While I am still lacking a proper debug setup for the Pico, maybe this is something you could try to reproduce and take a look?

Edit:
Just checked on Win 11 23H2 where this isn't reproducible as stated above. On MacOS 15.2 it is.

kosekmi, 2025-01-22:
Response from @Tails86 in  https://github.com/OrangeFox86/DreamcastControllerUsbPico/pull/124#issuecomment-2605298783

yeah, ok. It sounds like something going on with the peripheral handling somewhere then. I'll try to reproduce. If you are able to, could you maybe log the serial messages being sent/received and their timestamps?

I only have Linux/Windows environments I can play with over here.

kosekmi, 2025-01-22:
I generated a Maple Message Log capturing the issue: [sa2_debug.log](https://github.com/user-attachments/files/18510631/sa2_debug.log)

Setup: MacOS 15.2, Sonic Adventure 2. VSCode addon "Serial Monitor" sniffs on the serial port. Debug build of host-1p which enables serial port mirroring.

1. Load Save State with Level of Rogue: VMU LCD changes to Rogue
2. Running around the Level, getting hit 2 times which triggers Rumble
3. Pause Game, select Exit. Title Screen appears: VMU LCD changes to SA2 Logo
4. VMU LCD SA2 Logo is send every ~10-30ms in the title screen
5. Shortly after, the VSCode addon does not log any more messages
6. Maple Bus is unresponsive: No VMU LCD Update or Rumble, and no message mirroring
7. Cross check: Stop Flycast, move to the VSCode addon and send any Maple Message (e.g., "X 0E 02 00 02 00 00 01 00 10 F0 3B 05" for Rumble). Same behaviour as 6.
8. Reconnect USB - everything is working again

kosekmi, 2025-01-22:
The "coincidence" with the high frequency of messages got me thinking, and I can now reproduce the issue with a simple setup.

```
std::string values[] = {"X 0E 02 00 02 00 00 01 00 10 F0 3B 05\r\n", "X 0E 02 00 02 00 00 01 00 10 00 0F 00\r\n"};
int index = 0;

while (true) {
    asio::async_write(serial_handler, asio::buffer(values[index]), asio::transfer_exactly(values[index].size()), [ &serial_handler](const asio::error_code& error, size_t bytes_transferred)
    {
        if (error) {
            serial_handler.cancel();
        }
    });
    DEBUG_LOG(INPUT, "%s", values[index].c_str());
    index = (index + 1) % 2;
    std::this_thread::sleep_for(std::chrono::milliseconds(1));
}
```

The Code sends Rumble [On/Off] in quick succession. When sleeping 10ms between messages everything is fine, when using 1ms the Maple Bus becomes unresponsive after ~3s. So it seems it comes down to message frequency, probably in conjunction with their size.

kosekmi, 2025-01-22:
Addition to the setup: When using larger messages, e.g., sending VMU LCD Messages like below (oscillating between 2 images for visual comparison), the issue is reproducible on a 30ms timer. So message frequency in conjunction with their size seems to be the issue.

Note: we need to use asynchronous writes in Flycast to prevent emulation limiting, so this might also factor in.

`std::string values[] = {"X 0C 01 00 32 00 00 00 04 00 00 00 00 68 00 3F C0 02 01 FC 01 C0 3C 0C 03 FE 06 00 07 98 07 6F 08 00 71 F0 0E FF 10 00 0C 60 1F FF 60 00 02 30 3F 6D C0 00 01 18 36 FF 83 01 F0 14 7F FF BD 06 0E 10 7F 6D CE 38 07 A0 F6 FF 8B C8 07 C0 FF C3 0F 0C 05 40 7F 1F 1F 0E 05 60 7E 67 FD 0B 87 3F C7 8F EB 0D FF F8 F1 33 55 0A BF FF 3D 46 AB 0D 55 63 E1 0F 55 0A AA A0 7B 3A AA 05 55 60 21 E3 56 06 AA A0 3C 82 AA 05 55 60 27 07 56 02 AA A0 21 06 AA 03 55 40 20 07 54 01 AA C0 20 0D AC 00 D5 40 60 1C F8 00 6A 80 70 14 10 00 3F 00 50 22 00 00 18 00 48 22 00 00 0E 00 88 41 00 00 00 00 84 41 00 00 00 01 04 80 80 00 00 01 02\r\n", "X 0C 01 00 32 00 00 00 04 00 00 00 00 00 00 01 FF 80 00 00 00 1F FF F0 00 00 00 7F FF FC 00 00 41 FF FF FE 00 00 63 FF FF E3 00 00 77 FF FF F8 80 00 7F FF FF FE 00 FF FF FF FF FF FF FF E2 A3 6D 1B 15 80 1B 23 65 D1 11 80 12 2B 61 15 55 80 1A AA 29 D5 51 FE 12 2A 2D 15 9B E0 3F FF FF FF FF C0 30 E2 31 C3 C1 80 70 62 11 81 81 80 F0 22 11 00 81 8F FE 22 01 08 8F 80 3E 22 01 18 81 80 3C 22 21 10 F1 C0 30 62 21 00 81 E0 30 E2 31 81 81 FF F1 E2 31 C3 83 FF FF BF FF 7F FF 01 E0 00 00 0C 00 00 B0 00 00 18 00 00 DE 00 00 30 00 00 63 E0 00 60 00 00 30 00 01 C0 00 00 1C 00 07 00 00 00 07 00 7C 00 00 00 01 FF C0 00 00\r\n"};`

Tails86, 2025-01-22:
Thanks for the detailed report! I'll find some time this week to dig through it.

kosekmi, 2025-01-23:
Minimal test which forces the issue using the same `async_write()` handlers as in Flycast: [test.zip](https://github.com/user-attachments/files/18517744/test.zip)

Run on Linux (Debian/Ubuntu):
1. `sudo apt install libboost-all-dev`
2. Update serial port in Line 37
3. `g++ -o test test.cpp -lboost_system -lpthread`
4. Execute

By default the `Rumble` test case is used, change to `VMU LCD` in lines 8-16

Tails86, 2025-01-24:
I was able to replicate in a very specific way.

I tried creating a Python equivalent, [dctest.py.txt](https://github.com/user-attachments/files/18529176/dctest.py.txt), but I couldn't replicate this issue through Python on either Windows or Linux.

I tried compiling your sample code on Windows (using Conan package manager), but that didn't replicate it there.

My native Linux machine is Ubuntu18 which contained versions of boost and cmake that were too for me to use the code directly or use the most recent Conan release, so I gave up there. (I'll update that later 😝 )

I was able to attach the controller to WSL on my windows machine by opening powershell in Administrator and executing:
```
usbipd list
```
I noted the bus ID of the device labeled `USB Input Device, USB Mass Storage Device, USB Serial Dev...` then executed:
```
usbipd wsl attach --busid <ID>
```
It showed up under my WSL instance as `/dev/ttyACM0`. I compiled your sample code, and I think I finally replicated this!

What's odd for me is if I kill execution and restart it, the controller starts responding again for a while. This didn't sound like your experience though. I assumed that you need to remove and reattach to get things working again. Can you confirm?

Tails86, 2025-01-24:
I'm sort of wondering if this has anything to do with this issue?
https://www.boost.org/doc/libs/1_79_0/doc/html/boost_asio/reference/async_write/overload1.html
> The program must ensure that the stream performs no other write operations (such as async_write, the stream's async_write_some function, or any other composed operations that perform writes) until this operation completes.

kosekmi, 2025-01-24:
> The program must ensure that the stream performs no other write operations (such as async_write, the stream's async_write_some function, or any other composed operations that perform writes) until this operation completes.

> This seems to be the more appropriate way of doing things: [test.cpp.txt](https://github.com/user-attachments/files/18530733/test.cpp.txt)

> But of course, this is less asynchronous as desired. The service needs to be reset every time it runs out of work. I remember dealing with asio in the past, and I'm just now realizing THAT is why I had issues 🤦. I have had luck with adding a dummy boost::asio::io_service::work to an io_service just to make sure it never runs out of work. Then you can just run io_service.run() in another thread. Call io_service.stop() when it's time to exit. You'll still need to ensure you're not calling async_write before the previous write has completed. There isn't anything wrong with calling async_write from the callback that gets triggered though (I've done this without issue)

Thanks much, that seemed to be the issue! Closing this issue here, will update Flycast later

Closed 2025-01-24.

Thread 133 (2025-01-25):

Allow random access on memory

Tails86, 2025-01-25:
The MSC feels more like proof-of-concept rather than a fully fleshed out implementation. I pulled samples from TinyUSB in order to barely get things working. It only supports full copy or paste of file. Things get weird if the USB host starts requesting random areas of memory.

Tails86, 2025-02-08:
Random access is already accommodated. It's starting to come back to me that the issue I was having was that some programs wanted to write temporary data outside of the 128K limit of the file. That can't really be accommodated. The code handling the storage device does need a lot of TLC in general, but I don't know if there is anything else that can be done to allow link in this way. I think we're going the HID route for flycast integration instead anyway.

Tails86, 2025-02-08:
Oh yeah, and I got the feeling that this was Windows doing something stupid rather than the program itself

Closed 2025-02-08.

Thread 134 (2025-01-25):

Various cleanup work

Tails86, 2025-01-25:
There are a few things that have been floating in my mind about organizing/refactoring this project:

1. Create a more concise project description
    - I've struggled with what this project is meant to be. Is it a pure library or applications? If it is both, then that should be somehow summarized into 1 or 2 sentences exactly what is being achieved here. The pictures help, but the project statement still makes this project sound like a library rather than application.
    - Starting with "Maple Bus" may be confusing to those who don't know what "Maple Bus" is
2. Explain why isolation circuitry is important without getting too into the nitty-gritty
    - I don't think I explain well enough why option "1" is not ideal
3. Move or delete "Why the RP2040 is a Game Changer"
    - It's interesting, but it detracts from the "big picture" that needs to be described first
	- I wrote this before other RP2040 maple bus projects started popping up, so the language needs to be changed
4. Change help line in FlycastCommandParser to explain that "X" is reserved for flycast usage
5. Help text that gets printed isn't pretty - too many newlines
6. Fix tests
7. Auotmatic build and test in CI!

Closed 2025-01-26.

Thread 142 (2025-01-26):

Update the dependent pico-sdk

Tails86, 2025-01-26:
I used my own flavor of pico-sdk just because it took raspberrypi a year to update their TinyUSB dependency, and I needed a couple of fixes that I submitted to that repo. That update was made several months ago, so this project may finally go back to depending on the main pico-sdk repo.

Closed 2025-01-26.

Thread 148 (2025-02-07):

Make images for rp2350 (raspberry pi pico 2) and W variants

Tails86, 2025-02-07:
- Code needs to be recompiled to target RP2350
- The LED in the W variants is accessed differently. It would be nice if this could be determined and automatically correct at runtime, but another set of images is also feasible.

Closed 2025-02-08.

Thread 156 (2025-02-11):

Various minor enhancements

Tails86, 2025-02-11:
- Bump USB interface version to 0x0102 (I intend on updating flycast to check this to determine port number)
- Make the gamepad interfaces go in ascending order (I had done descending because some things would enumerate in descending order, but that seems like a crapshoot)
- Switch P1 -> DreamPort A, P2 -> DreamPort B, etc
- Add A, B, C, D icons to default screens for host-4p mode, and add commanding to change this to what is selected on flycast
- Change number of buttons based on controller index - this will provide a better hint as to which controller this is for MacOS (since SDL doesn't support path and interface ID 😞 for Mac)
- Add a command to print out serial number over serial
- Commit image-to-cmd and cmd-to-image scripts I made

kosekmi, 2025-02-11:
> Add A, B, C, D icons to default screens for host-4p mode, and add commanding to change this to what is selected on flycast

This is also useful for `host-1p`, e.g., when a `host-1p` DreamPort is configured to be Bus ID `C` in Flycast.

Closed 2025-02-14.

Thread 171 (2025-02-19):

Host: Power supply issue when using Raspberry Pi Pico Zero

rpf16rj, 2025-02-19:
Hi, i using a Raspberry Pi Pico Zero and when i connect to PC and connect a Dreamcast Controller, the USB is disconnect and Windows shows the warn:

"Unknow USB device need more power of than provided capacity."

I verified the wire connection of DC port and is correct.

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

Tails86, 2025-02-19:
I see that the device is popping up which rules out mis-wiring, and I can see from your provided pictured that it is wired up right. I have received another report recently that getting a powered USB hub may be necessary to properly power the controller with the VMU and purupuru attached. @nexus382, can you comment on that one?

rpf16rj, 2025-02-19:
But in my case, only detect when don't connect DC controller on rp2040. When i connect DC controller, he disconnect and show warn of power supply, without VMU and Rumble connected. I will test with a powered hub and back.

Thanks.

Tails86, 2025-02-19:
Ah! In that case, I suggest you check your wiring. I seem to have similar color wires, and on mine yellow is +5v, green + gray are ground. I think what is happening is a direct short from +5 V to ground occurs when you plug the controller in.

Tails86, 2025-02-19:
You should be referring to the left side of this image for the socket side connecting to the Pico.
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

I have a feeling that you may have mirrored things because my SDCKA and SDCKB colors to gp10 and gp11 are reversed from yours on my cable. I'll update some of this documentation to be a bit more clear in the future.

rpf16rj, 2025-02-19:
Oh my gosh, you are right,  i was inverted 5v pin with GND, i need take more attenption. Thanks for advise me.
Thank you for help and congratulations for this project.

Now is working:

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

rpf16rj, 2025-02-19:
Sure, can keep open.

This one VMU with blacklight is a little dark, i has another that blacklight is better.

nexus382, 2025-02-21:
im actually trying to do this for the vmus i have, and for a few friends, which guide/item list todid u go by to do yours if you do not mind me asking.

rpf16rj, 2025-02-21:
> im actually trying to do this for the vmus i have, and for a few friends, which guide/item list todid u go by to do yours if you do not mind me asking.

Sure, basically, I took a broken LCD screen from an old phone and removed the leds and screen difusors papers. I cut it for the screen size of VMU and made a wire connection to the leds from the 5v pin from VMU, with a 200omhs resistor to reduce the light power.

I follow this guide:
https://www.youtube.com/watch?v=7OAy7e_PmBo

rpf16rj, 2025-02-26:
> yes! so I must use a powered hub with my pico2, and when using my rumble AND my vmu. so to make sure were working fine, Just use the VMU, ensure proper functionality... because i can rock a VMU no issue... and if im not mistaken, I can do rumble with no VMU, but sucking enough power to rock that motor AND the vmu, to much with out a powered pico.
>
> also.. we using the resistors? try removing them if you are. otherwise, just go get your self a cheapass powered usbhub, (a hub that plugs in to a power outlet)

Hi, I'm back again. I noticed that in some games that use Purupack in an insane way, like Ferrari 350, when the Purupack begins to rumble, the joypad restarts (the VMU screen shows the QRcode again).
I tested with connected directly with a USB and a powered hub USB.

Tails86, 2025-02-27:
Thanks, I'll try to replicate that this weekend

Tails86, 2025-03-02:
I tested a few different things. I couldn't replicate this through my docking station or directly connected to my laptop. This does sound like what @nexus382 was running into. You may need to try a different powered hub or maybe even power it with a beefier external power source.

I measured current draw when vibration was going crazy, and I peaked at 190 mA. I can't really get instantaneous readings though, so there may be a larger spike that I'm not picking up.

I did run into trigger issues due to interactions between SDL2 and DInput on Windows. I applied a workaround on Feb 16. Try the latest and let me know if you still have trigger issues: https://github.com/flyinghead/flycast/actions/runs/13564228724

Tails86, 2025-03-03:
You could also try putting a capacitor between 5v and ground on the pico

Tails86, 2025-03-03:
Yeah, the more I think about it, the more I feel like a capacitor would be necessary to run some of these jump packs. If they included a capacitor inside the jump pack, they may have dried up by now. Something like 100 uf at 15V (or higher) would probably be more than enough to handle any dips. I'll do some more testing to see if I can replicate this on other systems/jump packs and see if this fixes the issue.

rpf16rj, 2025-03-04:
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

Hi @Tails86, thanks for your answer. I tried this version of flycast, same issue occurs.

I will try another power supply for my USB hub.

I already tried putting a 100uF capacitor on 5v and gnd of pico, but I think that didn't resolve this issue, so I'll try again.

Tails86, 2025-03-04:
Interesting! You might want to try artifacts here: https://github.com/OrangeFox86/DreamPicoPort/actions/runs/13658788047/artifacts/2690290692

I'm working on improving many things within this branch. A couple of changes which may help your situation:
1. The startup vibration was removed which may be causing reboot loops in some situations when input power is restricted
2. The disconnect timeout value was extended from about 30 ms up to about 160 ms

rpf16rj, 2025-03-05:
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

I just tried this build and wit capacitor 100uf, same issue.
I dont' noticeed reconnect, but the right trigger stop work and some times, the analogic stick is like reset the center position, for eg: When this ocurres, if i was pressing the right trigger, the full pressed position is 0% presset, when release trigger, nothing happing.
And if I was movin left stick to right for eg and relese left stick, he keep moving to right.

Tails86, 2025-03-05:
I'd like to get more data points on this issue. Do you mind seeing if this still happens when no VMU is attached and just Purupuru pack? If you still have the issue with that, can you try with just the VMU?

rpf16rj, 2025-03-05:
> I'd like to get more data points on this issue. Do you mind seeing if this still happens when no VMU is attached and just Purupuru pack? If you still have the issue with that, can you try with just the VMU?

With just VMU attached, this issue doesn't occur. With only Purupack attached, the problem occurs.
I have a USB power meter like this https://myvolts.com/imgs/prd/656/0/S-HC-0516_4.jpg and noticed that delivery power is around 4.7v with my USB hub powered. So as my USB power input used an old power cable, I soldered a USB-C female connector directly to use my best USB cable and power supply. Now I have 5.01v and 117mAh showing on USB meter screen, and the issue ocurrs again.
I don't think that is a low power issue. Maybe the rumble rotation does energy back again to Pico? I already see some circuits using a diode to previne somethink with this.

Tails86, 2025-03-05:
On the regular pico board, the difference between VBUS and VSYS is that VSYS is 5V after the on-board diode. I think the zero doesn't have a diode. It wouldn't hurt to try throwing one in there if you have a diode laying around.

nexus382, 2025-03-06:
can I ask and share what my test have shown?

When using a volt meter i seem to be around 3.01-3.4 V ocming thru for my controller and pico 2. htisis what is running when i test the grounds to the 5v line. I am very sure this is an AMPERAGE not VOLTAGE issue.

When im not on a pwoered hub, i use crazy taxi as crazy dashes and limit breaks and i can ake my controllre go from High to AX vibration on my Tremmor pack which is also a MU so that is oe of the most power hungry. If i ru the vmu AND the rumble, when the rumble starts up or when its going nusts this can happen. If i unplug the VMU and leave the Ruble/MU it rarly happens. When im plugged in to my good powered hub, none of these happen.

this tells me a few thigs.

the restart that happens super fast ad pops up the mass storage window like when you plug the vmu/cntrolelr in, will occure, when i hit my amperage limit. and this is what you seem to be having.

other then this, if you have tried a different powreed hub, and stil get this, its somethng speciic with the zero, maye the diod above thats being mentioned? would be nice if you had multiple controlers and VMUS to try to pull more power with out a motor t otest your diod idea.

rpf16rj, 2025-03-06:
Did test with a diode in5839 between 5v pin of pico zero and 5v pin of controller, the issue ocurres again. I did a new test with comon rp2040 pico and back results.

Tails86, 2025-03-07:
I don't really have much of an idea as to what could be happening here. Just summarizing what I know:
- When a motor first turns on, there is normally a large power draw to get it running (static voltage, high current as nexus382 describes).
    - You've tried adding a capacitor to help power the motor during this period
- When a motor turns off, there might possibly be a voltage kick back as the motor spins down (inductance). I would assume that a nicely built jump pack would account for this in its electronics, but who knows?
    - You've tried adding a diode to ensure these spikes are not fed back to the pico or USB port.
    - (The capacitor should help a bit with this too - to absorb and smooth out these spikes)
- What you are describing sounds likes the USB interface is completely disconnecting which means either the USB port is reacting to a large power draw and shutting off the port or the pico itself is momentarily shutting off
    - You've tried a completely separate voltage source without success

At this point, I'm wondering if it's your purupuru pack. Does this function properly in a real Dreamcast?

rpf16rj, 2025-03-09:
My Purupack works normally, but it is true that it isn't original, but on Dreamcast real hardware, I don't have any problem.

rpf16rj, 2025-03-09:
Today i will test with Raspberry Pico instead zero version.

Tails86, 2025-03-30:
This documentation is hopefully a little less confusing: https://github.com/OrangeFox86/DreamPicoPort/wiki/Installation-Guide#for-host-mode

I did realize that I never called out that top ground wire (what is labeled as 6 in the link above). I wonder if not having that connected would cause issues.

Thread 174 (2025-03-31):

Host: LED not working right

Tails86, 2025-03-31:
The LED is no longer operating as expected. It doesn't always shut off then a button is pressed, and sometimes will shut off and not turn back on.

This seems to clear up after leaving plugged in for a little while.

Tails86, 2025-04-01:
This seems like it's due to yet another Windows update/glitch that messes with the operation of the USB port. The serial port is accessible, but no communication can be made until the device has been plugged in for a few minutes on my system. It seems like the `usb_task()` is getting blocked for some reason.

Tails86, 2025-04-01:
This was a problem with my local config. I was playing with `usbipd`, so the device was automatically sharing with WSL. All I needed to do was `usbipd unbind --all` in an admin poweshell window.

Closed 2025-04-01.

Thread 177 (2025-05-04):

Upload Rev 1.0 board files

Tails86, 2025-05-04:
I fixed a few issues with the Rev 0.2 board after working with them a bit:
- Bridging the boxed connections for the simple config is a bit of a pain without a piece of wire. This is updated to use contacts that are closer together so that a solder bridge is possible.
- Added a resistor for LED output (useful when J1 is populated and used with a DC controller port module)
- Opened up the 2 board holes to allow M2.5 screws
- Moved A, B, C, D labels down
- Adjusted some part positions to make tracks a little more direct

Tails86, 2025-05-26:
Also noticed that the 68-ohm 0603 resistors don't have high enough wattage to support the fault case. I want to update that to 1206 and have boards made & tested before merging.

Closed 2025-06-15.

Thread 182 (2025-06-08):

Please help me Pico

Hunk4TH, 2025-06-08:
Hey guys,

I bought a Pi Pico and a Dreamcast extension cable and kinda f'd up by pulling the wires from the connector before labling them.  Is there a way I can find the right wires with maybe a meter tester or?

Tails86, 2025-06-08:
You can go grab a multimeter with a continuity tester [like this one](https://a.co/d/2mMLuD2). You could even program the pico to be a continuity tester using its LED.

Hunk4TH, 2025-06-08:
> You can go grab a multimeter with a continuity tester [like this one](https://a.co/d/2mMLuD2). You could even program the pico to be a continuity tester using its LED.

Awesome! I have one of those! So using this should point me in the right direction on where to solder the wires? I'm kicking myself for not lsbing them :/ sorry if this is a dumb question. I've only used a multimeter a few times.

Tails86, 2025-06-08:
If your multimeter has this symbol: 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
it should beep whenever you touch two contacts with the same potential. With that, you can poke a contact of the connector with one end then touch each wire until you hear a beep. If you don't have a continuity tester on your multimeter, you can just set it to resistance (ohm) (Ω) and monitor the display for 0 instead of listening for a beep.

nexus382, 2025-06-10:
ok 1
Did u install the CORRECT softtware?

2.. you DID verify PROPERLY the conncetions? bc it sounds like maybe a wire issue

3. Can u send a picture, and giev me more explination on what setup you are using? any resistors?

4. try with no rumble/vmu, see if flycast sees the device in th controllers page with nothing plugged in  to it

Hunk4TH, 2025-06-13:
Since I don't use the forth port on my Dreamcast, I've been tempted to remove it for this project but would rather not. I'm kinda desperate 😂

Tails86, 2025-06-13:
In case this helps, this is the color coding of cables I buy from Amazon
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

Hunk4TH, 2025-06-14:
Sweet! I might buy those then. Do you have a link? That image will definitely help! I'm sorry if I was being a pain.

Tails86, 2025-06-14:
That would be this one
https://a.co/d/0Ti3X9a

Hunk4TH, 2025-06-15:
I got it wired up maybe I'm still missing something? The vmu lights up and beeps but that's it nothing else.

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

Hunk4TH, 2025-06-15:
I was wondering if the wire being long would be an issue myself. I tried swapping with no luck. I'm gonna try again tomorrow. Maybe I should use some wick to remove all the wires and try again fresh? I figured having wires on the Pico would be more convenient instead of soldering directly from the extension cable.

Yes, the Pico led does light up and in the USB game controller settings it even picks it up as a "DreamPicoPort" same with the latest Flycast.

nexus382, 2025-06-16:
ok we need you to do this.,

login to discord and send me a friedn request
Nexus222

we need to tlk back and forth easier then this and we will solve it in a minute or 2.

Closed 2025-07-12.

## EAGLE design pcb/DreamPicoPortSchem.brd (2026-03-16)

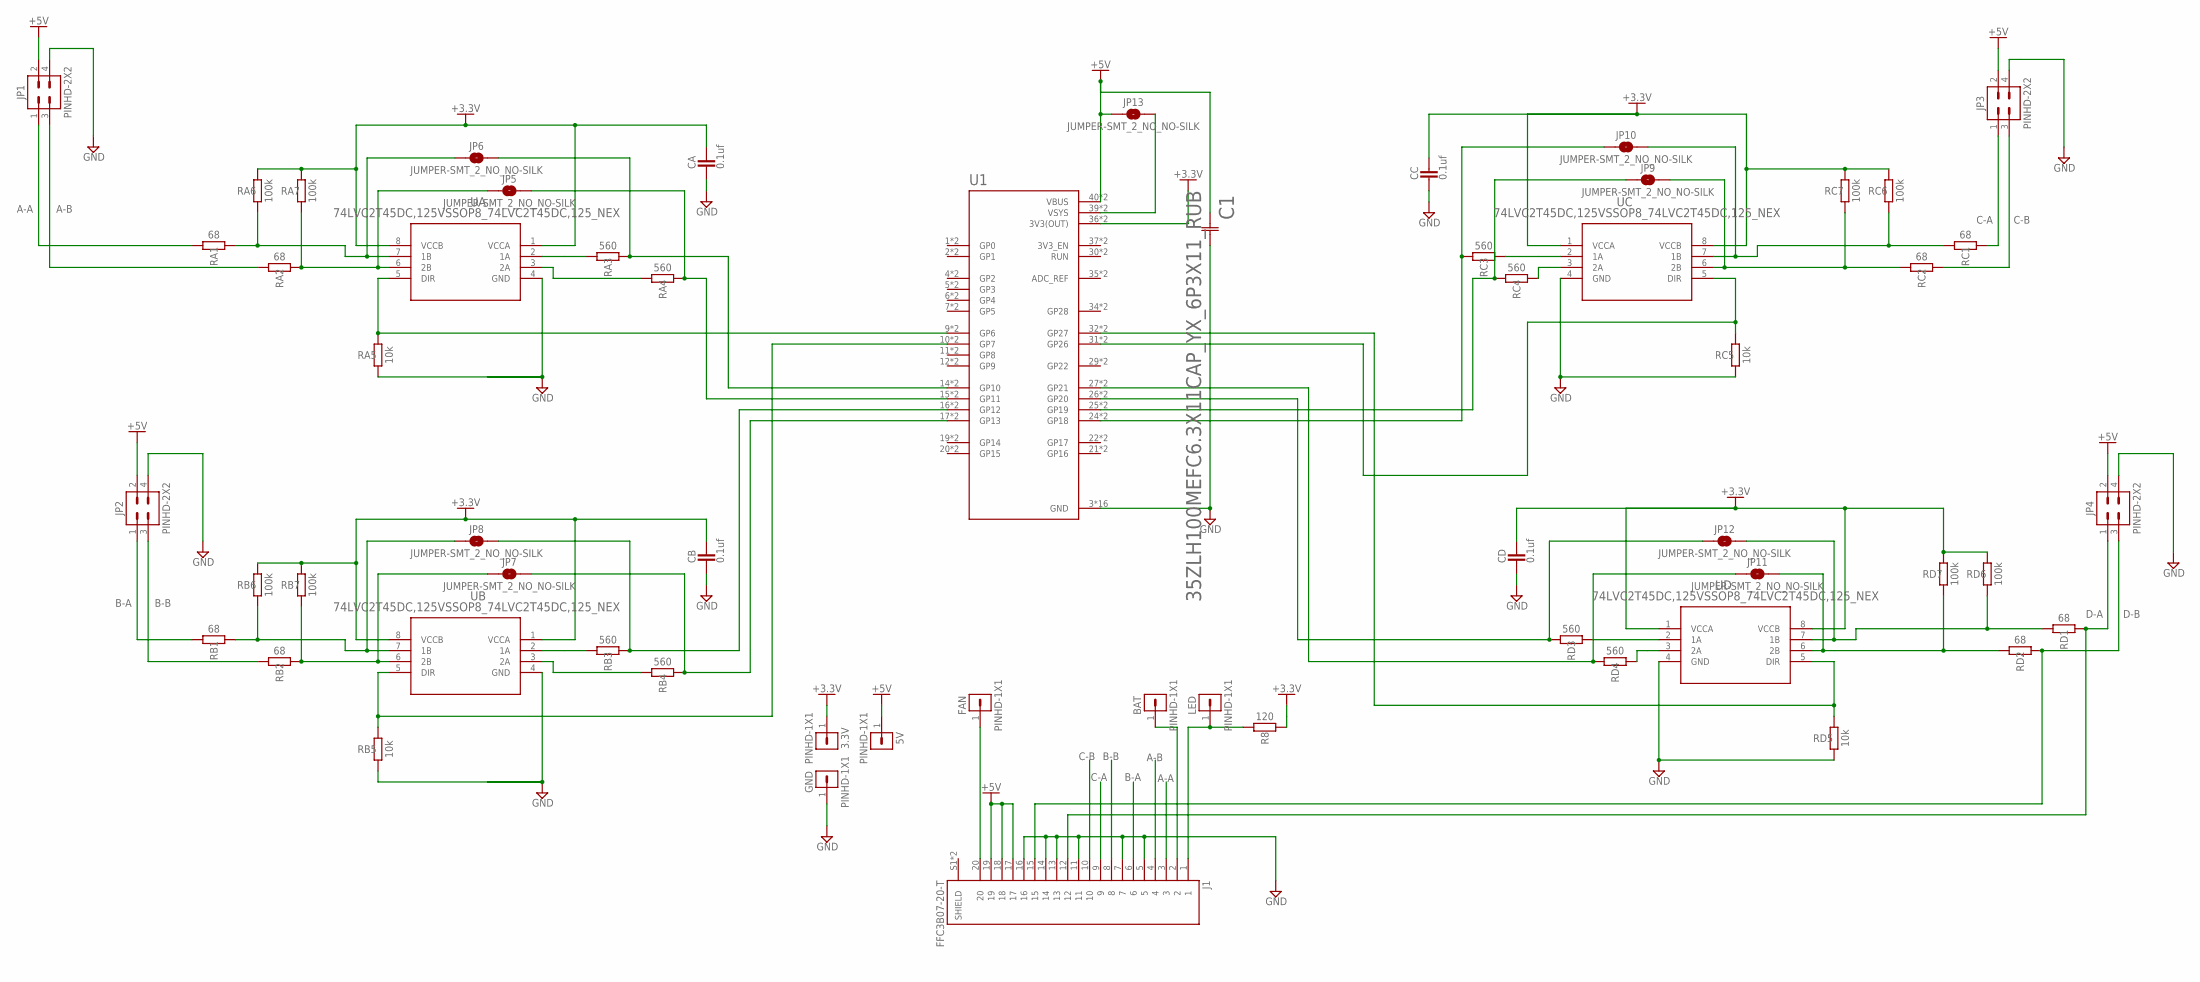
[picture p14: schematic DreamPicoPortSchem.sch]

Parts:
3.3V, 5V: PINHD-1X1; 1X01
BAT: PINHD-1X1; 1X01
C1: 35ZLH100MEFC6.3X11CAP_YX_6P3X11_RUB; CAP_YX_6P3X11_RUB
CA: 0.1uf; CAPC1608X85
CB: 0.1uf; CAPC1608X85
CC: 0.1uf; CAPC1608X85
CD: 0.1uf; CAPC1608X85
FAN: PINHD-1X1; 1X01
GND: PINHD-1X1; 1X01
J1: FFC3B07-20-T; GCT_FFC3B07-20-T
JP1, JP2, JP3, JP4: PINHD-2X2; 2X02
JP5, JP6, JP7, JP8, JP9, JP10, JP11, JP12, JP13: JUMPER-SMT_2_NO_NO-SILK; SMT-JUMPER_2_NO_NO-SILK
LED: PINHD-1X1; 1X01
R8: 120; RESC1608X60
RA1, RA2: 68; RESC3216X70
RA3: 560; RESC1608X60
RA4: 560; RESC1608X60; RATING 4
RA5: 10k; RESC1608X60
RA6, RA7: 100k; RESC1608X60
RB1, RB2: 68; RESC3216X70
RB3: 560; RESC1608X60
RB4: 560; RESC1608X60; RATING 4
RB5: 10k; RESC1608X60
RB6, RB7: 100k; RESC1608X60
RC1, RC2: 68; RESC3216X70
RC3, RC4: 560; RESC1608X60
RC5: 10k; RESC1608X60
RC6, RC7: 100k; RESC1608X60
RD1, RD2: 68; RESC3216X70
RD3, RD4: 560; RESC1608X60
RD5: 10k; RESC1608X60
RD6, RD7: 100k; RESC1608X60
U1: RASPBERRY_PICO-NO_DEBUG; PICO-PKG-NO_DEBUG
UA: 74LVC2T45DC,125VSSOP8_74LVC2T45DC,125_NEX; VSSOP8_74LVC2T45DC,125_NEX
UB: 74LVC2T45DC,125VSSOP8_74LVC2T45DC,125_NEX; VSSOP8_74LVC2T45DC,125_NEX
UC: 74LVC2T45DC,125VSSOP8_74LVC2T45DC,125_NEX; VSSOP8_74LVC2T45DC,125_NEX
UD: 74LVC2T45DC,125VSSOP8_74LVC2T45DC,125_NEX; VSSOP8_74LVC2T45DC,125_NEX

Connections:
+3.3V: 3.3V.1, CA.1, CB.1, CC.1, CD.1, R8.1, RA6.2, RA7.2, RB6.2, RB7.2, RC6.2, RC7.2, RD6.2, RD7.2, U1.36 (3V3(OUT)), U1.P$36 (3V3(OUT)), UA.1 (VCCA), UA.8 (VCCB), UB.1 (VCCA), UB.8 (VCCB), UC.1 (VCCA), UC.8 (VCCB), UD.1 (VCCA), UD.8 (VCCB)
+5V: 5V.1, C1.1, J1.17, J1.18, J1.19, JP1.2, JP2.2, JP3.2, JP4.2, JP13.1, U1.40 (VBUS), U1.P$40 (VBUS)
A-A: J1.3, JP1.1, RA1.1
A-B: J1.4, JP1.3, RA2.1
B-A: J1.6, JP2.1, RB1.1
B-B: J1.8, JP2.3, RB2.1
C-A: J1.9, JP3.1, RC1.2
C-B: J1.10, JP3.3, RC2.2
D-A: J1.12, JP4.1, RD1.2
D-B: J1.15, JP4.3, RD2.2
GND: C1.2, CA.2, CB.2, CC.2, CD.2, GND.1, J1.5, J1.7, J1.11, J1.13, J1.14, J1.16, JP1.4, JP2.4, JP3.4, JP4.4, RA5.1, RB5.1, RC5.1, RD5.1, U1.3 (GND), U1.8 (GND), U1.13 (GND), U1.18 (GND), U1.23 (GND), U1.28 (GND), U1.33 (GND), U1.38 (GND), U1.P$3 (GND), U1.P$8 (GND), U1.P$13 (GND), U1.P$18 (GND), U1.P$23 (GND), U1.P$28 (GND), U1.P$33 (GND), U1.P$38 (GND), UA.4 (GND), UB.4 (GND), UC.4 (GND), UD.4 (GND)
unnamed: RA5.2, U1.9 (GP6), U1.P$9 (GP6), UA.5 (DIR)
unnamed: RD3.1, UD.2 (1A)
unnamed: JP6.2, RA3.1, U1.14 (GP10), U1.P$14 (GP10)
unnamed: RB3.2, UB.2 (1A)
unnamed: RA4.2, UA.3 (2A)
unnamed: JP5.1, RA2.2, RA7.1, UA.6 (2B)
unnamed: JP6.1, RA1.2, RA6.1, UA.7 (1B)
unnamed: RC5.2, U1.31 (GP26), U1.P$31 (GP26), UC.5 (DIR)
unnamed: FAN.1, J1.20
unnamed: BAT.1, J1.2
unnamed: JP10.1, RC3.2, U1.24 (GP18), U1.P$24 (GP18)
unnamed: RB5.2, U1.10 (GP7), U1.P$10 (GP7), UB.5 (DIR)
unnamed: JP8.2, RB3.1, U1.16 (GP12), U1.P$16 (GP12)
unnamed: RD4.1, UD.3 (2A)
unnamed: JP7.2, RB4.1, U1.17 (GP13), U1.P$17 (GP13)
unnamed: RB4.2, UB.3 (2A)
unnamed: J1.1, LED.1, R8.2
unnamed: JP8.1, RB1.2, RB6.1, UB.7 (1B)
unnamed: JP7.1, RB2.2, RB7.1, UB.6 (2B)
unnamed: RA3.2, UA.2 (1A)
unnamed: JP5.2, RA4.1, U1.15 (GP11), U1.P$15 (GP11)
unnamed: JP9.1, RC4.2, U1.25 (GP19), U1.P$25 (GP19)
unnamed: RC4.1, UC.3 (2A)
unnamed: JP13.2, U1.39 (VSYS), U1.P$39 (VSYS)
unnamed: JP10.2, RC1.1, RC6.1, UC.7 (1B)
unnamed: JP9.2, RC2.1, RC7.1, UC.6 (2B)
unnamed: RC3.1, UC.2 (1A)
unnamed: JP12.1, RD3.2, U1.26 (GP20), U1.P$26 (GP20)
unnamed: JP11.1, RD4.2, U1.27 (GP21), U1.P$27 (GP21)
unnamed: RD5.2, U1.32 (GP27), U1.P$32 (GP27), UD.5 (DIR)
unnamed: JP12.2, RD1.1, RD6.1, UD.7 (1B)
unnamed: JP11.2, RD2.1, RD7.1, UD.6 (2B)

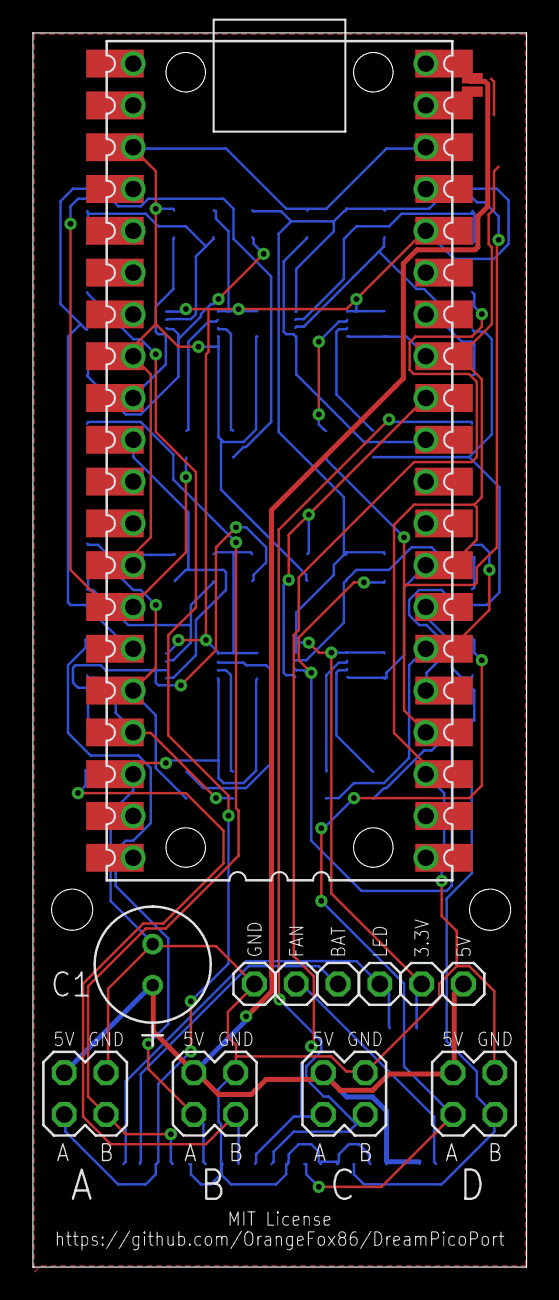
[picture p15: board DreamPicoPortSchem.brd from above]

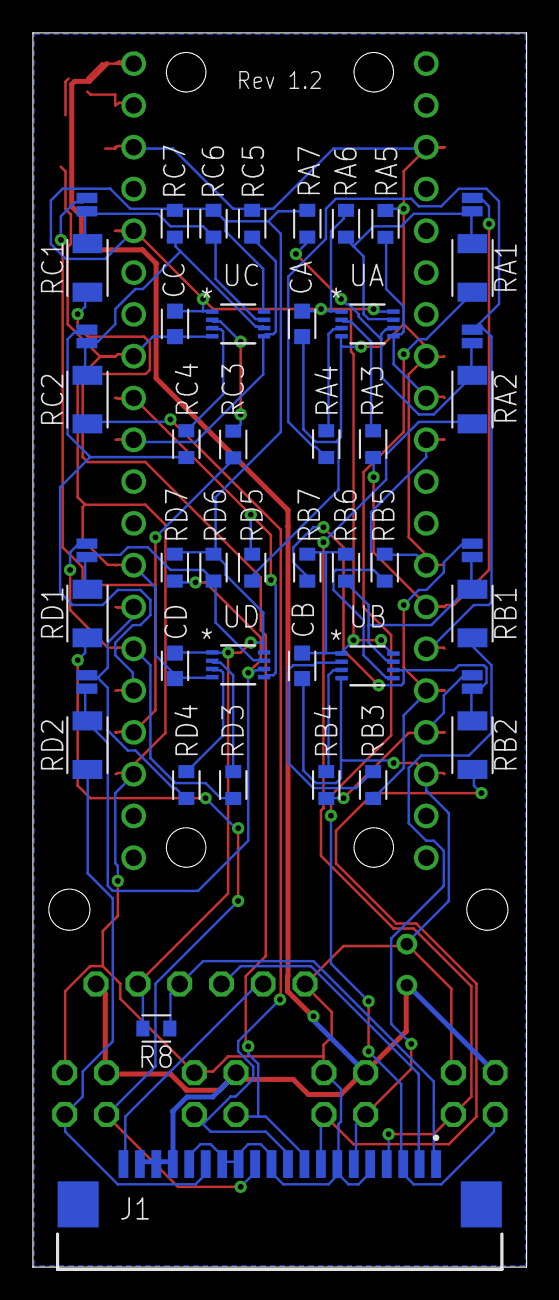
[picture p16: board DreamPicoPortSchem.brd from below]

Board: 2 copper layers, 30.0 x 75.0 mm, 59 parts (46 on the bottom side), 43 nets.

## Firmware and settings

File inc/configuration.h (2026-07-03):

// MIT License
//
// Copyright (c) 2022-2026 The DreamPicoPort Contributors
// https://github.com/OrangeFox86/DreamcastControllerUsbPico
//
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
#ifndef __CONFIGURATION_H__
#define __CONFIGURATION_H__

// true to setup and print debug messages over UART0 (pin 1, 115200 8N1)
// Warning: enabling debug messages drastically degrades communication performance
#ifdef _DEBUG
    #define SHOW_DEBUG_MESSAGES true
#else
    #define SHOW_DEBUG_MESSAGES false
#endif

// Adjust the CPU clock frequency here (133 MHz is maximum documented stable frequency)
#ifndef CPU_FREQ_KHZ
    #define CPU_FREQ_KHZ 133000
#endif

// The minimum amount of time we check for an open line before taking control of it
// Set to 0 to completely disable this check
#define MAPLE_OPEN_LINE_CHECK_TIME_US 10

// Amount of time in nanoseconds at which each bit transmits (value should be divisible by 3)
// 480 ns achieves just over 2 mbps, just as the Dreamcast does
#define MAPLE_NS_PER_BIT 480

// Added percentage on top of the expected write completion duration (for write timeout)
#define MAPLE_WRITE_TIMEOUT_EXTRA_PERCENT 20

// Added time in microseconds on top of the expected write completion duration (for write timeout)
// This accounts for any static delays caused by ISR execution
#define MAPLE_WRITE_TIMEOUT_EXTRA_US 1000

// Estimated nanoseconds before peripheral responds - this is used for scheduling only
#define MAPLE_RESPONSE_DELAY_NS 50

// Maximum amount of time waiting for the beginning of a response when one is expected
#define MAPLE_RESPONSE_TIMEOUT_US 1000

// Estimated nanoseconds per bit to receive data - this is used for scheduling only
// 1750 was selected based on the average time it takes a Dreamcast controller to transmit each bit
#define MAPLE_RESPONSE_NS_PER_BIT 1750

// Maximum amount of time in microseconds to pass in between received words before read is canceled
// Dreamcast controllers sometimes have a ~180 us gap between words, so 300 us accommodates for that
#define MAPLE_INTER_WORD_READ_TIMEOUT_US 300

// The pin which sets IO direction for each player (-1 to disable)
#ifndef P1_DIR_PIN
    #define P1_DIR_PIN 6
#endif
#ifndef P2_DIR_PIN
    #define P2_DIR_PIN 7
#endif
#ifndef P3_DIR_PIN
    #define P3_DIR_PIN 26
#endif
#ifndef P4_DIR_PIN
    #define P4_DIR_PIN 27
#endif

// True if DIR pin is HIGH for output and LOW for input; false if opposite
#ifndef DIR_OUT_HIGH
    #define DIR_OUT_HIGH true
#endif

// The start pin of the two-pin bus for each player
#ifndef P1_BUS_START_PIN
    #define P1_BUS_START_PIN 10
#endif
#ifndef P2_BUS_START_PIN
    #define P2_BUS_START_PIN 12
#endif
#ifndef P3_BUS_START_PIN
    #define P3_BUS_START_PIN 18
#endif
#ifndef P4_BUS_START_PIN
    #define P4_BUS_START_PIN 20
#endif

// LED pin number for USB activity or -1 to disable
// When USB connected:
//   Default: ON
//   When controller key pressed: OFF
// When USB disconnected:
//   Default: OFF
//   When controller key pressed: Flashing quick
#ifndef USB_LED_PIN
    #define USB_LED_PIN 25
#endif

// LED pin number for simple USB activity or -1 to disable
// ON when USB connected; OFF when disconnected
#ifndef SIMPLE_USB_LED_PIN
    #define SIMPLE_USB_LED_PIN -1
#endif

#endif // __CONFIGURATION_H__

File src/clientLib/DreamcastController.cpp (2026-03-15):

// MIT License
//
// Copyright (c) 2022-2026 The DreamPicoPort Contributors
// https://github.com/OrangeFox86/DreamcastControllerUsbPico
//
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
#include "DreamcastController.hpp"
#include <string.h>

namespace client
{

DreamcastController::DreamcastController() :
    DreamcastController({
        .enLeftD = true,
        .enRightD = false,
        .enLeftA = true,
        .enRightA = true,
        .enL = true,
        .enR = true,
        .enStart = true,
        .enA = true,
        .enB = true,
        .enC = true,
        .enD = true,
        .enX = true,
        .enY = true,
        .enZ = true
    })
{}

DreamcastController::DreamcastController(EnabledControls enabledControls) :
    DreamcastPeripheralFunction(DEVICE_FN_CONTROLLER),
    mEnabledControls(enabledControls),
    mConditionSamples(0)
{
    updateConditionMasks();
    setCondition(NEUTRAL_CONTROLLER_CONDITION);
}

void DreamcastController::setEnabledControls(EnabledControls enabledControls)
{
    mEnabledControls = enabledControls;
    updateConditionMasks();
}

void DreamcastController::updateConditionMasks()
{
    controller_condition_t andCondition;
    memset(&andCondition, 0xFF, sizeof(andCondition));
    controller_condition_t orCondition;
    memset(&orCondition, 0, sizeof(orCondition));

    if (!mEnabledControls.enA)
    {
        orCondition.a = 1;
    }

    if (!mEnabledControls.enB)
    {
        orCondition.b = 1;
    }

    if (!mEnabledControls.enC)
    {
        orCondition.c = 1;
    }

    if (!mEnabledControls.enD)
    {
        orCondition.d = 1;
    }

    if (!mEnabledControls.enL)
    {
        andCondition.l = 0;
    }

    if (!mEnabledControls.enLeftA)
    {
        andCondition.lAnalogLR = 0x80;
        andCondition.lAnalogUD = 0x80;
        orCondition.lAnalogLR = 0x80;
        orCondition.lAnalogUD = 0x80;
    }

    if (!mEnabledControls.enLeftD)
    {
        orCondition.up = 1;
        orCondition.down = 1;
        orCondition.left = 1;
        orCondition.right = 1;
    }

    if (!mEnabledControls.enR)
    {
        andCondition.r = 0;
    }

    if (!mEnabledControls.enRightA)
    {
        andCondition.rAnalogLR = 0x80;
        andCondition.rAnalogUD = 0x80;
        orCondition.rAnalogLR = 0x80;
        orCondition.rAnalogUD = 0x80;
    }

    if (!mEnabledControls.enRightD)
    {
        orCondition.upb = 1;
        orCondition.downb = 1;
        orCondition.leftb = 1;
        orCondition.rightb = 1;
    }

    if (!mEnabledControls.enStart)
    {
        orCondition.start = 1;
    }

    if (!mEnabledControls.enX)
    {
        orCondition.x = 1;
    }

    if (!mEnabledControls.enY)
    {
        orCondition.y = 1;
    }

    if (!mEnabledControls.enZ)
    {
        orCondition.z = 1;
    }

    memcpy(mConditionAndMask, &andCondition, sizeof(mConditionAndMask));
    memcpy(mConditionOrMask, &orCondition, sizeof(mConditionOrMask));
}

bool DreamcastController::handlePacket(const MaplePacket& in, MaplePacket& out)
{
    const uint8_t cmd = in.frame.command;
    if (cmd == COMMAND_GET_CONDITION)
    {
        ++mConditionSamples;
        out.frame.command = COMMAND_RESPONSE_DATA_XFER;
        out.reservePayload(3);
        out.appendPayload(getFunctionCode());
        out.appendPayload(mCondition, 2);
        return true;
    }
    return false;
}

void DreamcastController::reset()
{}

uint32_t DreamcastController::getFunctionDefinition()
{
    return (
        (mEnabledControls.enLeftD  ? 0x000000F0 : 0) |
        (mEnabledControls.enRightD ? 0x0000F000 : 0) |
        (mEnabledControls.enLeftA  ? 0x000C0000 : 0) |
        (mEnabledControls.enRightA ? 0x00300000 : 0) |
        (mEnabledControls.enL      ? 0x00020000 : 0) |
        (mEnabledControls.enR      ? 0x00010000 : 0) |
        (mEnabledControls.enStart  ? 0x00000008 : 0) |
        (mEnabledControls.enA      ? 0x00000004 : 0) |
        (mEnabledControls.enB      ? 0x00000002 : 0) |
        (mEnabledControls.enC      ? 0x00000001 : 0) |
        (mEnabledControls.enD      ? 0x00000800 : 0) |
        (mEnabledControls.enX      ? 0x00000400 : 0) |
        (mEnabledControls.enY      ? 0x00000200 : 0) |
        (mEnabledControls.enZ      ? 0x00000100 : 0)
    );
}

void DreamcastController::setCondition(controller_condition_t condition)
{
    uint32_t newCondition[2];
    memcpy(newCondition, &condition, sizeof(newCondition));

    for (uint32_t i = 0; i < 2; ++i)
    {
        mCondition[i] = (newCondition[i] & mConditionAndMask[i]) | mConditionOrMask[i];
    }
}

void DreamcastController::setControls(const Controls& controls)
{
    controller_condition_t condition;
    condition.l = controls.l2;
    condition.r = controls.r2;
    condition.a = !controls.south;
    condition.b = !controls.east;
    condition.c = !controls.r1;
    condition.x = !controls.west;
    condition.y = !controls.north;
    condition.z = !controls.l1;
    condition.d = !controls.l3;
    condition.start = !controls.start;

    condition.up = 1;
    condition.down = 1;
    condition.left = 1;
    condition.right = 1;
    switch(controls.hat)
    {
        case Hat::UP_LEFT:
            condition.up = 0;
            condition.left = 0;
            break;

        case Hat::UP_RIGHT:
            condition.up = 0;
            condition.right = 0;
            break;

        case Hat::UP:
            condition.up = 0;
            break;

        case Hat::DOWN_LEFT:
            condition.down = 0;
            condition.left = 0;
            break;

        case Hat::DOWN_RIGHT:
            condition.down = 0;
            condition.right = 0;
            break;

        case Hat::DOWN:
            condition.down = 0;
            break;

        case Hat::LEFT:
            condition.left = 0;
            break;

        case Hat::RIGHT:
            condition.right = 0;
            break;

        case Hat::NEUTRAL:
        default:
            // Neutral
            break;
    }

    condition.rAnalogUD = controls.ry;
    condition.rAnalogLR = controls.rx;
    condition.lAnalogUD = controls.ly;
    condition.lAnalogLR = controls.lx;

    // No secondary D-pad
    condition.upb = 1;
    condition.downb = 1;
    condition.leftb = 1;
    condition.rightb = 1;

    setCondition(condition);
}

uint32_t DreamcastController::getConditionSamples()
{
    return mConditionSamples;
}

} // namespace client

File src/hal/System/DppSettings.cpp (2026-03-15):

// MIT License
//
// Copyright (c) 2022-2026 The DreamPicoPort Contributors
// https://github.com/OrangeFox86/DreamcastControllerUsbPico
//
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
#include <cstdint>
#include <cstring>
#include <unordered_set>
#include <optional>

#include <configuration.h>

#include <hal/System/DppSettings.hpp>

#include <pico/stdlib.h>
#include <hardware/flash.h>
#include <hardware/irq.h>
#include <pico/platform.h>
#include <hardware/watchdog.h>
#include <pico/multicore.h>

#include <hal/System/LockGuard.hpp>
#include "CriticalSectionMutex.hpp"

static CriticalSectionMutex gSaveMutex;

static const uint32_t kMagic = 0xA875EBBB;

static const uint32_t kUsbEnableCdcMask = (1 << 0);
static const uint32_t kUsbEnableMscMask = (1 << 1);
static const uint32_t kUsbEnableWebusbAnnounceMask = (1 << 2);

struct SettingsMemory
{
	uint32_t magic;
    uint16_t size; // Number of 4-byte words, starting at CRC
    uint16_t invSize;
	uint32_t crc;
    uint32_t usbEn;
    uint8_t playerEnableMode[4];
    int32_t gpioA[4];
    int32_t gpioDir[4];
    uint8_t gpioDirOutputHigh[4];
    int32_t usbLedGpio;
    int32_t simpleUsbLedGpio;
    uint8_t dpadType;
    uint8_t unusedPad[3]; // unused for now, but can be used in the future
};

static const uint16_t kSettingsMemorySizeBytes = (sizeof(SettingsMemory) - offsetof(SettingsMemory, crc));
static const uint16_t kSettingsMemorySizeWords = (kSettingsMemorySizeBytes / 4);
static const uint16_t kMinimumSettingsMemorySizeWords = 14;

static_assert(sizeof(SettingsMemory) < FLASH_PAGE_SIZE, "Incorrect size");
static_assert(kSettingsMemorySizeBytes % 4 == 0, "Incorrect size");

static uint32_t __no_inline_not_in_flash_func(get_settings_flash_offset)()
{
    uint8_t txbuf[16] = {0x9f};
    uint8_t rxbuf[16] = {0};
    flash_do_cmd(txbuf, rxbuf, 16);

    // Last flash sector contains all settings
    // For pico 1, this should return (0x200000 - FLASH_SECTOR_SIZE)
    // For pico 2, this should return (0x400000 - FLASH_SECTOR_SIZE)
    return ((1 << rxbuf[3]) - FLASH_SECTOR_SIZE);
}

uint32_t __no_inline_not_in_flash_func(calc_crc32)(const uint32_t* ptr, uint16_t numWords)
{
    uint32_t crc = 0xFFFFFFFF;
    while (numWords-- > 0)
    {
        crc ^= *ptr++;
    }
    return crc;
}

std::optional<DppSettings> DppSettings::readSettingsAtAddr(uint32_t flashAddrOffset)
{
    const SettingsMemory* settingsMemory = reinterpret_cast<const SettingsMemory*>(
        XIP_BASE + flashAddrOffset
    );

    // check for validity
    if (
        settingsMemory->magic != kMagic ||
        ((settingsMemory->size ^ settingsMemory->invSize) != 0xFFFF) ||
        (settingsMemory->size < kMinimumSettingsMemorySizeWords) ||
        (calc_crc32(&settingsMemory->crc, settingsMemory->size) != 0)
    ){
        // Data in flash is invalid
        return std::nullopt;
    }

    DppSettings settings;
    settings.cdcEn = ((settingsMemory->usbEn & kUsbEnableCdcMask) > 0);
    settings.mscEn = ((settingsMemory->usbEn & kUsbEnableMscMask) > 0);
    settings.webUsbAnnounceEn = ((settingsMemory->usbEn & kUsbEnableWebusbAnnounceMask) > 0);
    settings.usbLedGpio = settingsMemory->usbLedGpio;
    settings.simpleUsbLedGpio = settingsMemory->simpleUsbLedGpio;
    for (uint8_t i = 0; i < kNumPlayers; ++i)
    {
        settings.playerDetectionModes[i] =
            static_cast<DppSettings::PlayerDetectionMode>(settingsMemory->playerEnableMode[i]);
        settings.gpioA[i] = settingsMemory->gpioA[i];
        settings.gpioDir[i] = settingsMemory->gpioDir[i];
        settings.gpioDirOutputHigh[i] = settingsMemory->gpioDirOutputHigh[i];
    }

    if (settingsMemory->size >= 15)
    {
        // Added in version 1.2.2
        settings.dpadType = static_cast<DppSettings::DpadType>(settingsMemory->dpadType);
    }

    return settings;
}

const DppSettings& DppSettings::initialize()
{
    // Settings at this address are written by this application at runtime
    sSettingsOffsetAddr = get_settings_flash_offset();

    std::optional<DppSettings> loadedSettings = readSettingsAtAddr(sSettingsOffsetAddr);
    if (loadedSettings.has_value())
    {
        sLoadedSettings = loadedSettings.value();
    }
    else
    {
        sLoadedSettings = DppSettings();
    }

    return sLoadedSettings;
}

const DppSettings& DppSettings::getInitialSettings()
{
    return sLoadedSettings;
}

void DppSettings::requestSave(uint32_t delayMs)
{
    LockGuard lock(gSaveMutex);

    if (!sSaveOrClearRequested)
    {
        sSaveRequestedSettings = *this;
        sDelayMs = delayMs;
        sSaveRequestTime = time_us_32();
        sSaveOrClearRequested = true;
    }
}

void DppSettings::requestClear(uint32_t delayMs)
{
    LockGuard lock(gSaveMutex);

    if (!sSaveOrClearRequested)
    {
        sSaveRequestedSettings = std::nullopt;
        sDelayMs = delayMs;
        sSaveRequestTime = time_us_32();
        sSaveOrClearRequested = true;
    }
}
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

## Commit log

2025-03-08 Button 21 (index 20) is used for peripheral connect/disconnect event
2025-03-09 Add binary data parsing to serial interface (#172)
    - Add binary data parsing to serial interface (using ASCII character 0x05 ENQUIRY)
    - Speed up CDC response by writing command directly to CDC rather than through STDIO
    - Added unit tests for the parser (fixed overflow recovery)
    - Added "XV" for flycast command version
    - Improved "X?" all status command
    - Added "XH0" for echo off and "XH1" for echo on
    - Serialize all responses from flycast command parser
    - Removed initial vibration when jump pack inserted
    - Increased controller disconnect period from about 40 ms to about 150 ms
    - Button 21 (index 20) is used for peripheral connect/disconnect event
    ---------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
    [MaplePacket.hpp]
2025-03-31 Added zero build configuration (#173)
    * Added zero build configuration
    * Removed installation instructions from the README since they now exist in the wiki
    * Added RP2350 to README
    ---------
    [configuration.h]
2025-05-04 175 upload board files (#176)
    Added PCB board files
    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
    [DreamPicoPortSchem.3mf, DreamPicoPortSchem.brd, DreamPicoPortSchem.sch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]
2025-05-26 178 minor improvements (#179)
    * 178: Increase CPU freq when pico2 used
    * 178: Fixed USB_CDC_ENABLED and added USB_MSC_ENABLED
    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
    [configuration.h]
2025-06-15 177: Uploaded Rev 1.0 board files (#180)
    * 177: Uploaded Rev 1.0 board files
    * 177: Changed R[A-D]1 and R[A-D]2 resistors to 1206 size
    * 177: Mask vias on PCB
    * 177: Added board examples
    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
    [DreamPicoPortSchem.3mf, DreamPicoPortSchem.brd, DreamPicoPortSchem.sch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]
2025-09-06 183 host add webusb (#184)
    - Added configurable settings
    - Added player detection capability
    - By default, poll each player. Once detection is made, permanently enable that controller.
    - Can be changed in settings
    - This removes the need to have 1, 2, 4 player variants of the binary as this can be configured at runtime by the user
    - Player detection modes: `Disabled`, `Enabled`, `Disabled, Enable On Detect`, `Auto`, `Auto, No Disable`
    - Added WebUSB interfaces, and all functionality may be accessed through this interface
    - Disable Mass Storage Class (MSC) by default but allow this to be enabled through the WebUSB interface
    - I am not going to support any issues with MSC goi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
    [configuration.h]
2025-11-24 Added 3D objects for case (#191)
    [DPP-Case-1P-BambuStudio.3mf, DPP-Case-1P-raw.3mf, DPP-Case-2P-BambuStudio.3mf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]
2025-12-01 190 dream pico port locks up using new api and flycast (#194)
    * 190: Fixed DEBUG_PRINT when SHOW_DEBUG_MESSAGES is true
    * 190: Added debug build and launch/attach configurations
    * 190: Prvent WebUsbInterface::vendorWrite() from looping forever
    * 190: Only continue writing if the previous write succeeded
    * 190: Bump version to 1.2.2
    [configuration.h]
2025-12-20 200 allow d pad to output to discrete buttons (#201)
    Added option to change the D-Pad output between hat enum, discrete buttons, or both
2026-01-04 204 dpp locks up (#207)
    - Ensure all direct USB operations are executed on core 0
    - Ensure button 21 is emitted on controller disconnect
    - Optimized watchdog handling
    - Fixed a few potential issues in webusb
    - Added optional callback to MapleBus (not used yet)
    [MapleBus.cpp]
2026-03-15 208 another lockup issue (#212)
    - Fixed lockup issue by ensuring I/O state is completely reset to defaults on timeout
    - Fixed a couple of issues on webpage
    - Updated copyright statements
    [configuration.h]
2026-03-16 Updated 5V to VBUS on PCB
    [DreamPicoPortSchem.3mf, DreamPicoPortSchem.brd, DreamPicoPortSchem.sch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]
2026-03-16 Make 5V rail thicker to support 1 A max current
    [DreamPicoPortSchem.3mf, DreamPicoPortSchem.brd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]
2026-05-24 Add udev note to settings page for linux (#221)
    A note about udev rule is now displayed when connection fails on settings page because of SecurityError and the current OS is Linux
2026-06-16 Fixed function code to hex conversion and added fn names 'Ext Storage' and 'Camera' (#222)
2026-07-03 Mark any data used by the ISR as volatile and ISR functions run entirely in RAM (#228)
    Refer to explanation here: https://github.com/OrangeFox86/DreamPicoPort/issues/227
    - Ensure ISRs are run entirely from RAM code
    - Removed the 64-bit timeout values and replaced it with a 32-bit timeout offset values
    - Move all code to RAM if compiling for pico2
    - Added system TTY processor
    - Added memory diagnostics which help determine how much RAM is available (much more than I expected!)
    [configuration.h]

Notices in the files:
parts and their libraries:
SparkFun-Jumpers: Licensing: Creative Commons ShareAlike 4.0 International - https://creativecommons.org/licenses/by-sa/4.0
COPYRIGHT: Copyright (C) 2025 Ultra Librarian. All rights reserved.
